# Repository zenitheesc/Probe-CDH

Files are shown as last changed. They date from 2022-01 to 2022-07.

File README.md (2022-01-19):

# Probe-CDH
<h1 align="center" style="color:white; background-color:black">Probe-CDH</h1>
<h4 align="center"> Telecommunication board for the Zenith's Stack architecture.</h4>

<p align="center">
	<a href="http://zenith.eesc.usp.br/">
    
    </a>
    <a href="https://eesc.usp.br/">
    
    </a>
    <a href="https://github.com/zenitheesc/Probe-CDH/blob/main/LICENSE">
    
    </a>
    <a href="https://github.com/zenitheesc/Probe-CDH/issues">
    
    </a>
    <a href="https://github.com/zenitheesc/Probe-CDH/commits/main">
    
    </a>
    <a href="https://github.com/zenitheesc/Probe-CDH/graphs/contributors">
    
    </a>
    <a href="https://github.com/zenitheesc/Probe-CDH/commits/main">
    
    </a>
    <a href="https://github.com/zenitheesc/Probe-CDH/issues">
    
    </a>
    <a href="https://github.com/zenitheesc/Probe-CDH/pulls">
    
    </a>
</p>

<p align="center">
    <a href="#environment-and-tools">Environment and Tools</a> •
    <a href="#Z-Hub">Z-Hub</a> •
    <a href="#Block-Diagram">Block Diagram</a> •
    <a href="#Schematic">Schematic</a> • 
    <a href="#Board">Board</a>
</p>

## Environment and tools

This board was designed using KiCad 5.1.10.

## Block Diagram

<p align = "center">
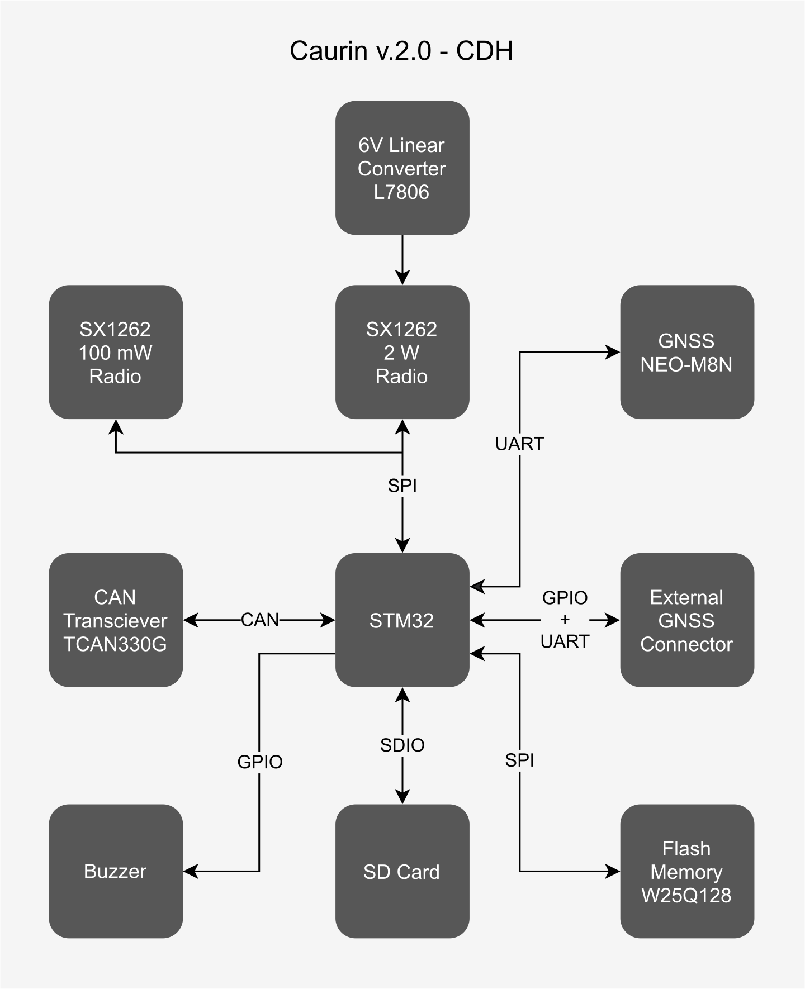
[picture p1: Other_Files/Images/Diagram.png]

</p>

## Z-Hub

This board contains a Stack Connector, with the 2021 Z-Hub pinout.

<table align = "center">
  <thead>
    <tr>
      <th colspan=2>   Z-Hub 2021   </th>
    </tr>
  </thead>
  <tbody>
    <tr>
      <td>GND</td>
      <td>GND</td>
    </tr>
    <tr>
      <td>GND</td>
      <td>GND</td>
    </tr>
    <tr>
      <td>BAT+</td>
      <td>BAT+</td>
    </tr>
    <tr>
      <td>SOl+</td>
      <td>SOl-</td>
    </tr>
    <tr>
      <td>5V</td>
      <td>5V</td>
    </tr>
    <tr>
      <td>3V3</td>
      <td>3V3</td>
    </tr>
    <tr>
      <td>MISO1</td>
      <td>MOSI1</td>
    </tr>
    <tr>
      <td>SCK1</td>
      <td>CAN_H</td>
    </tr>
    <tr>
      <td>SDA </td>
      <td>CAN_L</td>
    </tr>
    <tr>
      <td>SCL</td>
      <td>CE02</td>
    </tr>
    <tr>
      <td>CE11</td>
      <td>CE12</td>
    </tr>
    <tr>
      <td>SDA1</td>
      <td>SCL1</td>
    </tr>
    <tr>
      <td>SDA2</td>
      <td>SCL2</td>
    </tr>
    <tr>
      <td>TX1</td>
      <td>RX1</td>
    </tr>
    <tr>
      <td>TX2</td>
      <td>RX2</td>
    </tr>
    <tr>
      <td>DIG1</td>
      <td>DIG6</td>
    </tr>
    <tr>
      <td>ALRT1</td>
      <td>/CHRG</td>
    </tr>
    <tr>
      <td>PWM</td>
      <td>DIG8</td>
    </tr>
    <tr>
      <td>/FAULT</td>
      <td>DIG9</td>
    </tr>
    <tr>
      <td>DIG5</td>
      <td>DIG10</td>
    </tr>
  </tbody>
</table>

## Schematic

The design was separated in hierarchical sheets to accommodate all components in an orderly way.

The first page contains the STM32L476 with all its accompanying circuits; crystals, debugging LED, Boot solder jumper, decoupling capacitors and reset buttons. On the same page you find the stack connector along with a programming and debugging connector and an external GPS connector (can also be used for UART communication with external devices, it’s bad but it’s there).

<p align = "center">
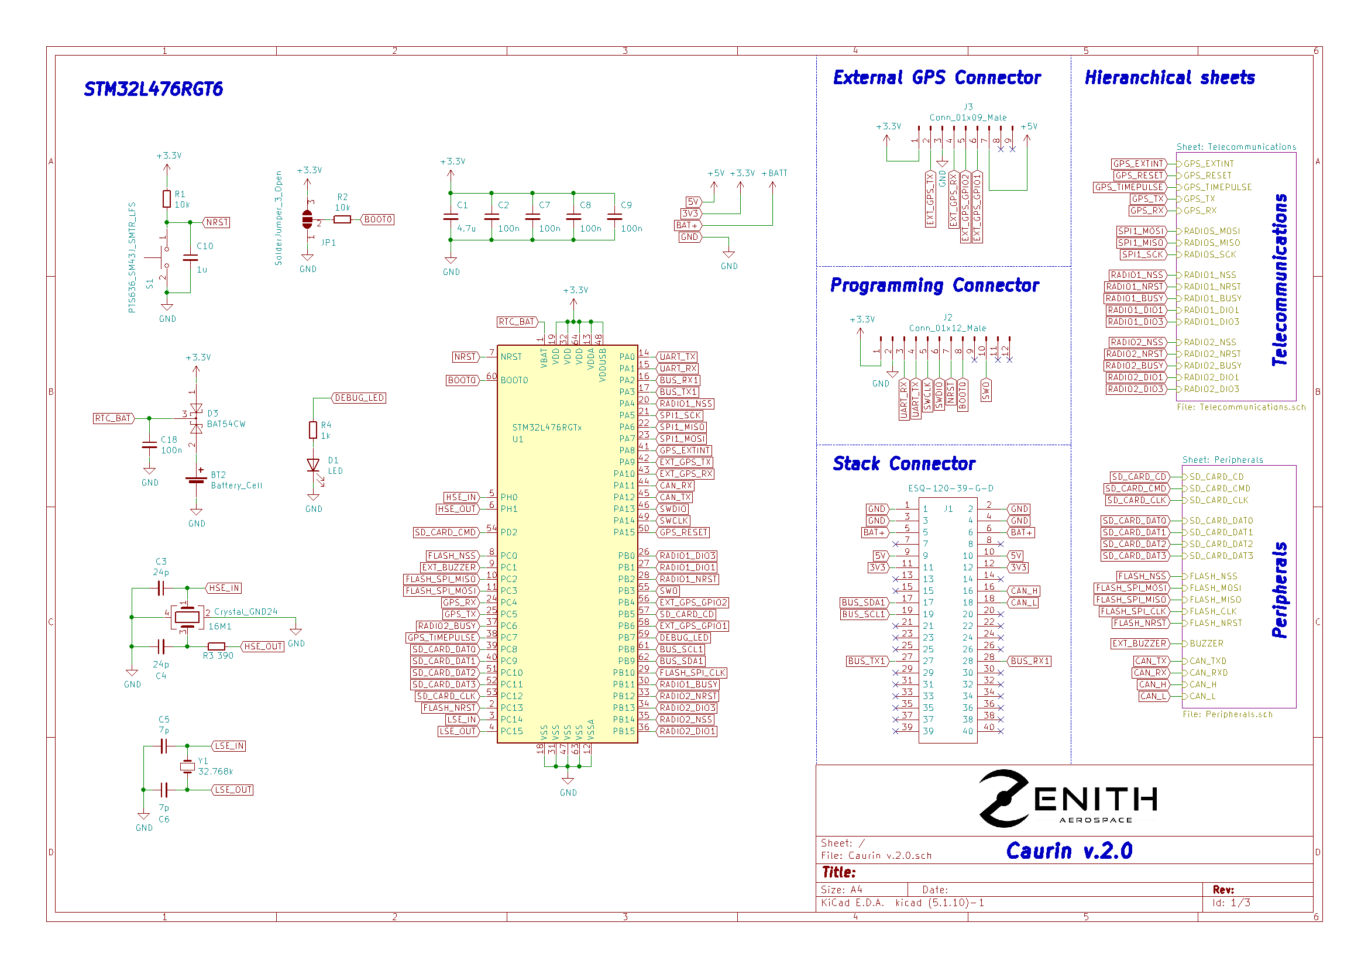
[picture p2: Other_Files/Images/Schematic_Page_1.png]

</p>

The second page contains the two LoRa and (G)FSK radios, one capable of 2 W off transmission power when fed with 6 V (obtained with the linear regulator), and the other capable of 160 mW, used as a backup or low power option. Both of them are based on the Semtech SX1262 transceiver, for operation at 915 MHz. The u-blox NEO-M8N also lives on this page, with its backup super capacitor for hot starts.

<p align = "center">
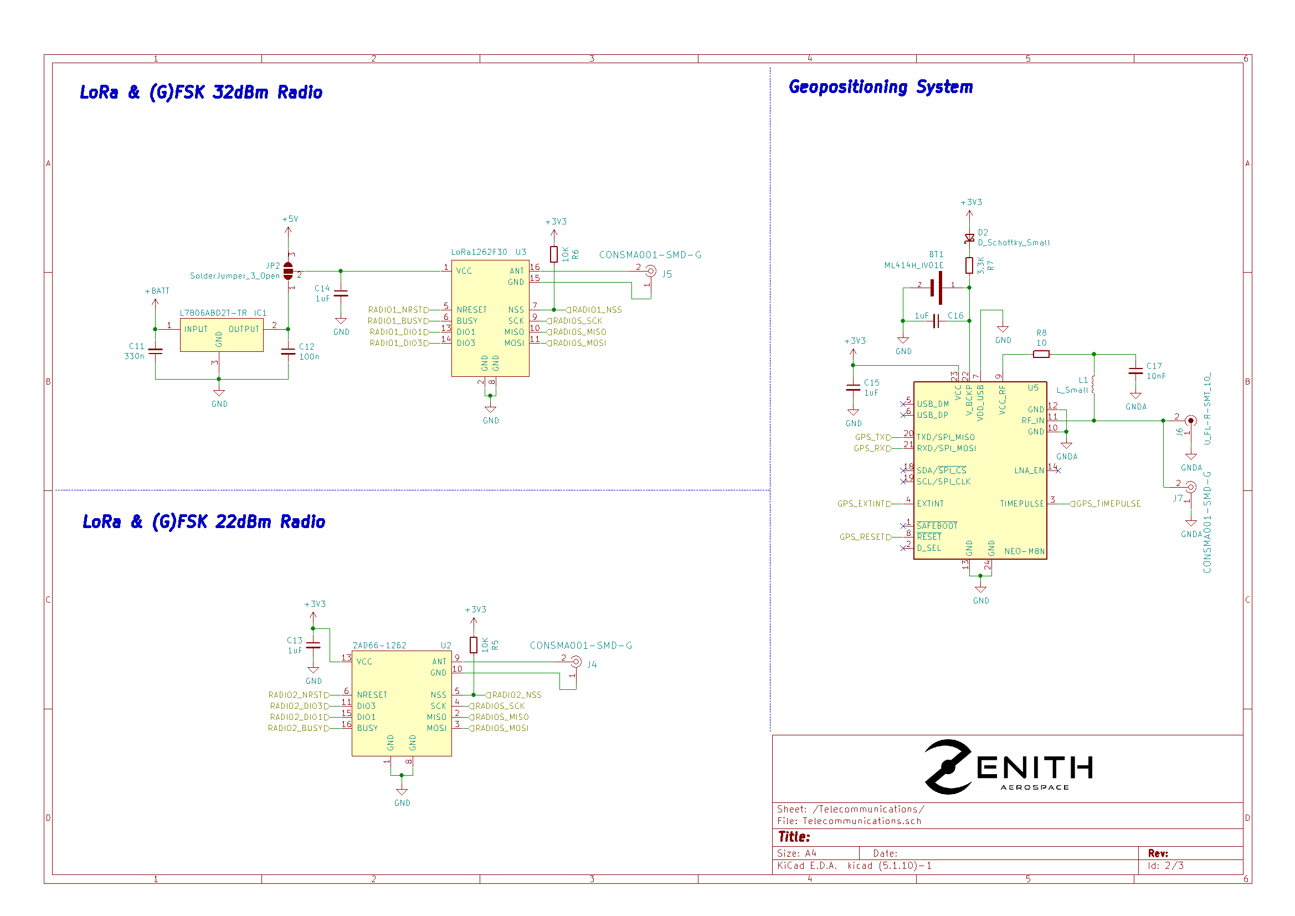
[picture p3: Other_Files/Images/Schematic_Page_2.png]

</p>

The last page houses the remaining peripherals which include the SD Card, the 128 Mb Flash, the CAN Transceiver and the buzzer connector with its mosfet, which may also be used as an external actuator with a max current of 1 A (the mosfet actually handles up to 1,5 A but let’s not push it too far).  

<p align = "center">
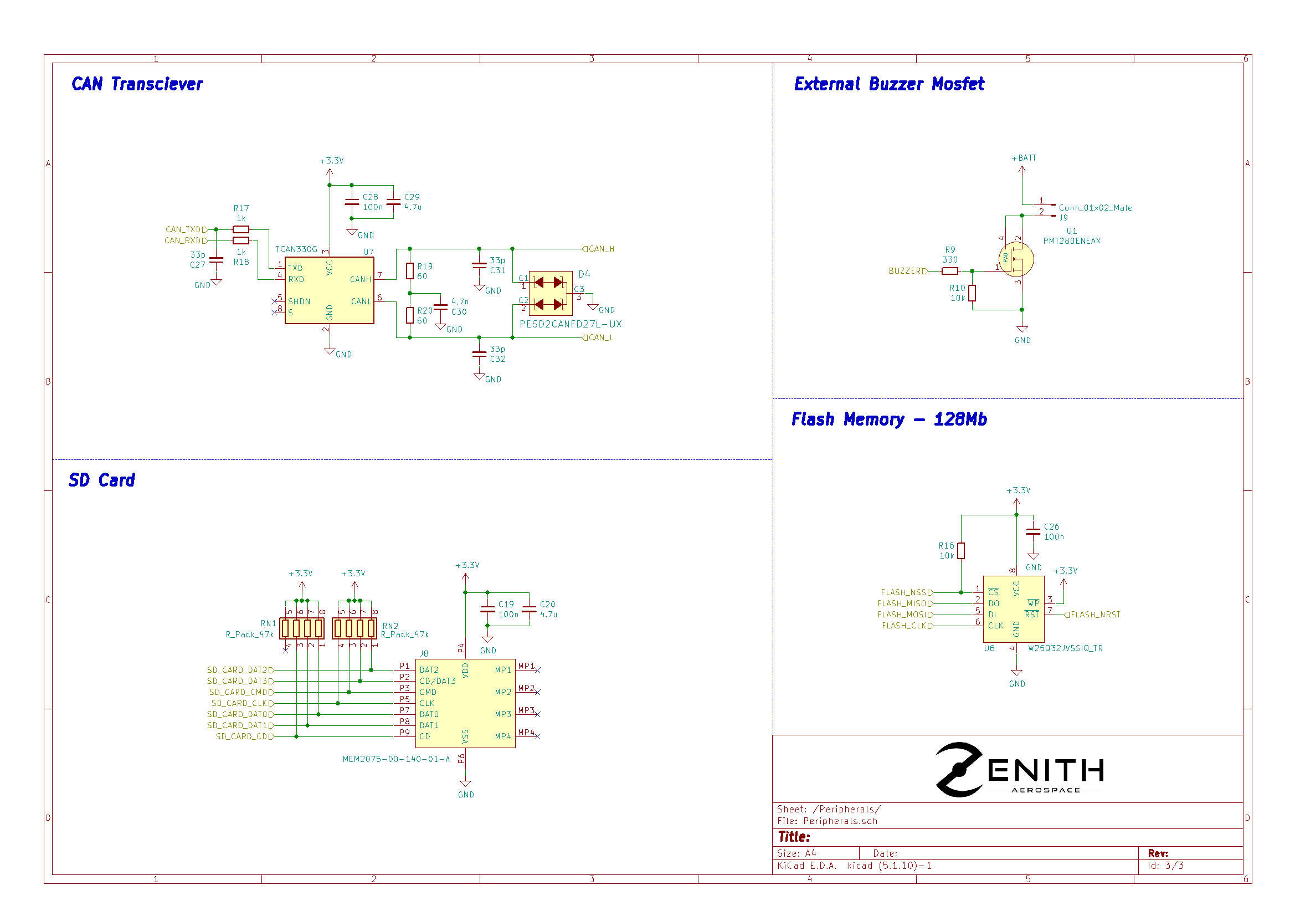
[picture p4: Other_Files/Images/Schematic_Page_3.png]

</p>

## Board

<p align = "center">
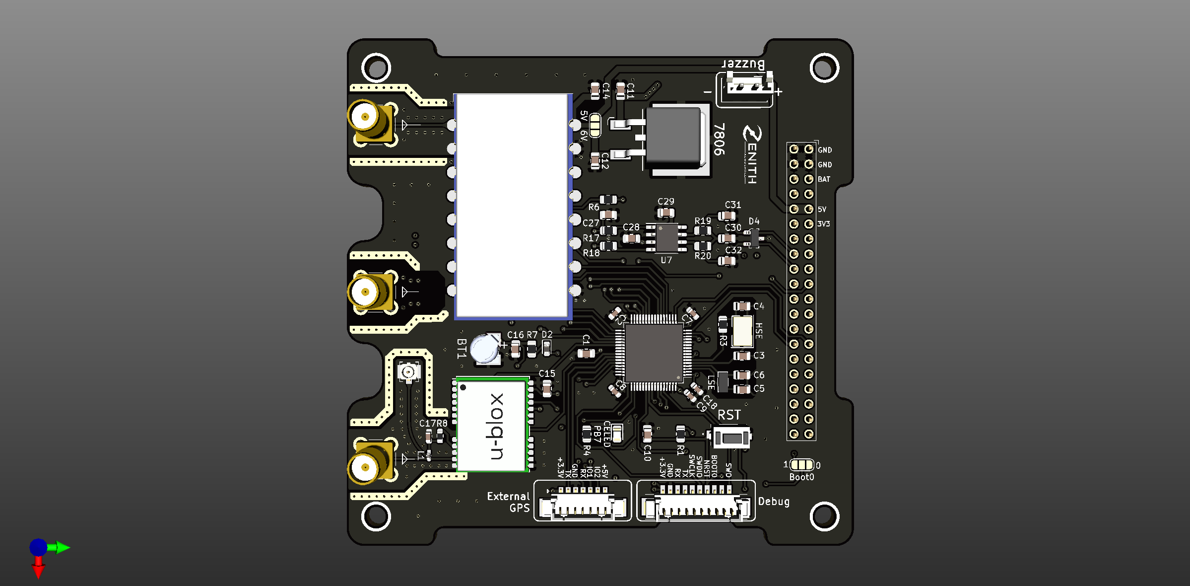
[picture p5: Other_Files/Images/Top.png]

</p>

<p align = "center">
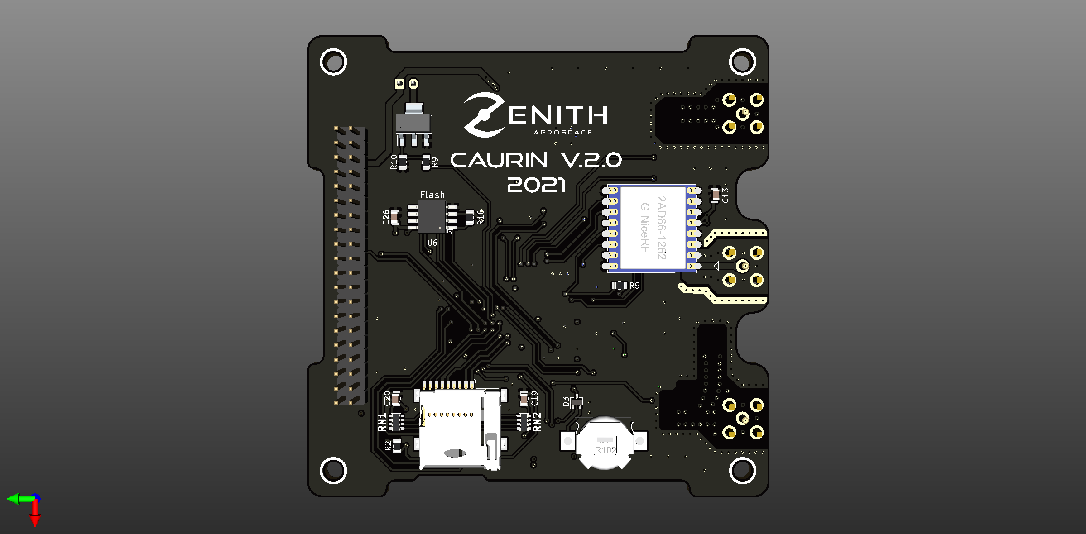
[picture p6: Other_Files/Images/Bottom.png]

</p>

<p align = "center">
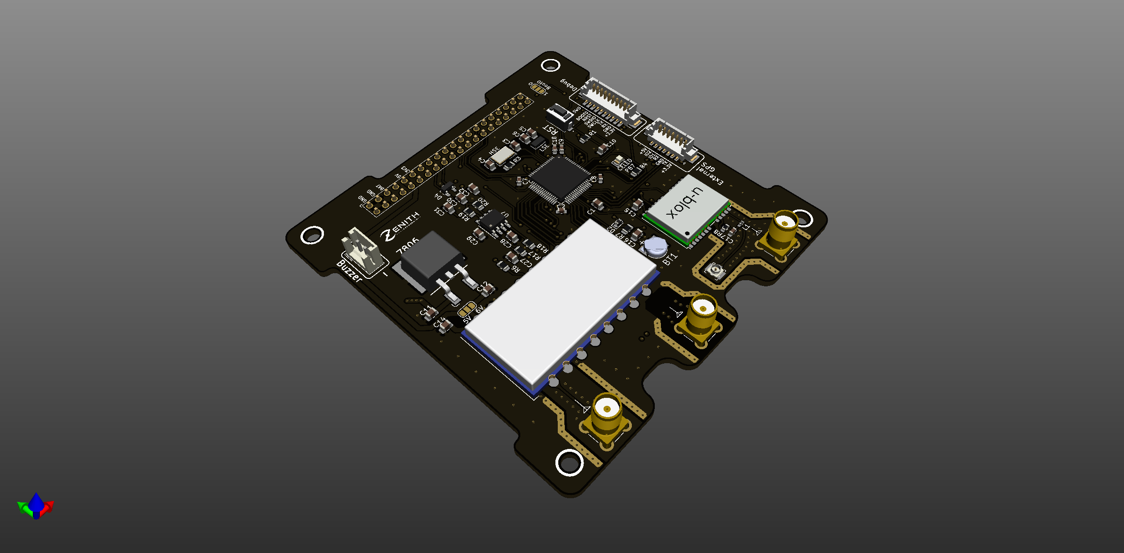
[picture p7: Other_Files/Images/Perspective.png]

</p>

---

<p align="center">
    <a href="http://zenith.eesc.usp.br">
    
    </a> 
    <a href="https://www.facebook.com/zenitheesc">
    
    </a> 
    <a href="https://www.instagram.com/zenith_eesc/">
    
    </a>

</p>
<p align = "center">
<a href="zenith.eesc@gmail.com">zenith.eesc@gmail.com</a>
</p>

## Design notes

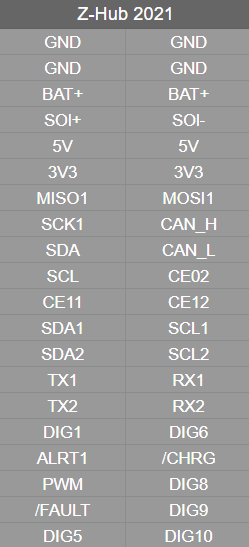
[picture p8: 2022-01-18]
Other_Files/Images/Z-Hub.png

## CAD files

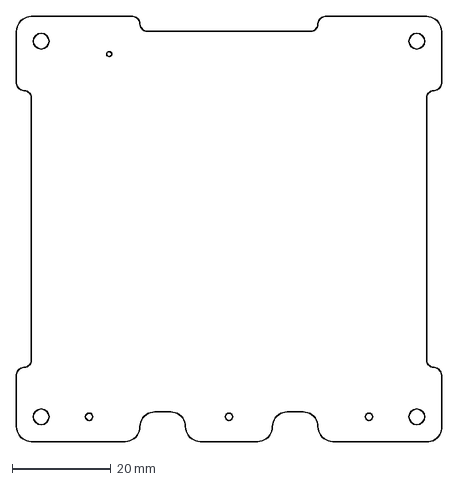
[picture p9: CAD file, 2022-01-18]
KiCad_Files/ModelStack.dxf
86.0 x 86.0 mm

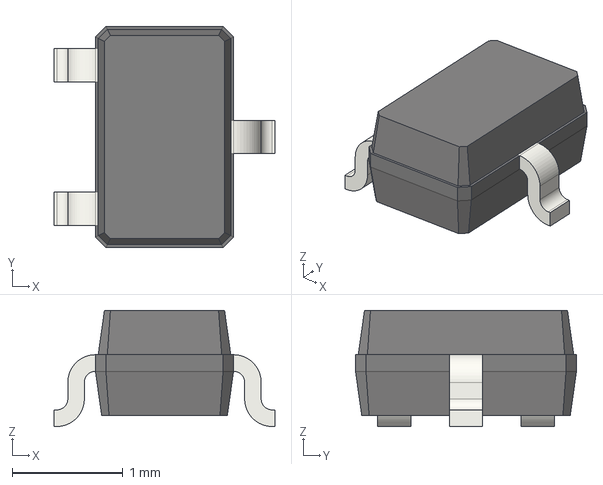
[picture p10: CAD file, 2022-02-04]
KiCad_Files/shapes3D/SOT-323_SC-70.step
2.00 x 2.00 x 1.05 mm

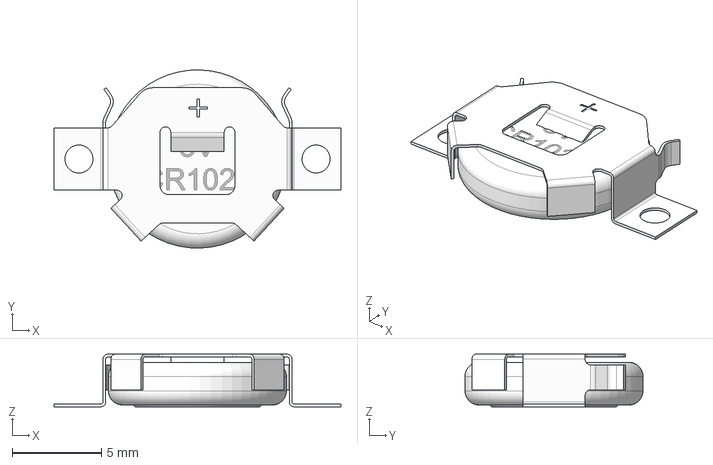
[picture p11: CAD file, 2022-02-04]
KiCad_Files/shapes3D/keystone-PN3030TR+ButtonCell.step
16.1 x 10.00 x 2.95 mm

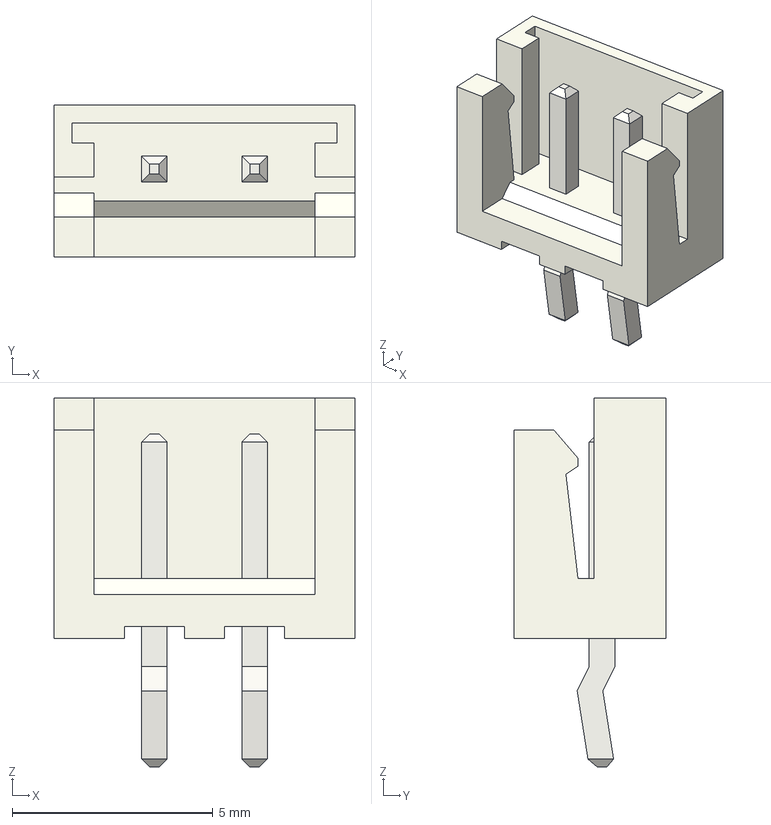
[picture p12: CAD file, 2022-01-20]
KiCad_Files/shapes3D/JST_EH_B2B-EH-A_1x02_P2.50mm_Vertical.step
7.50 x 3.80 x 9.20 mm

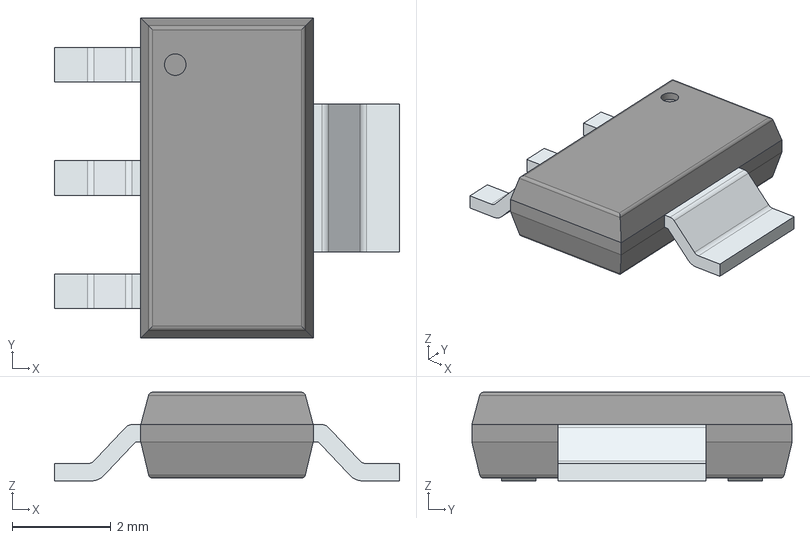
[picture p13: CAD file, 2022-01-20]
KiCad_Files/shapes3D/PMT280ENEAX.stp
7.00 x 6.50 x 1.80 mm
PinsArrayL
FilletPinR

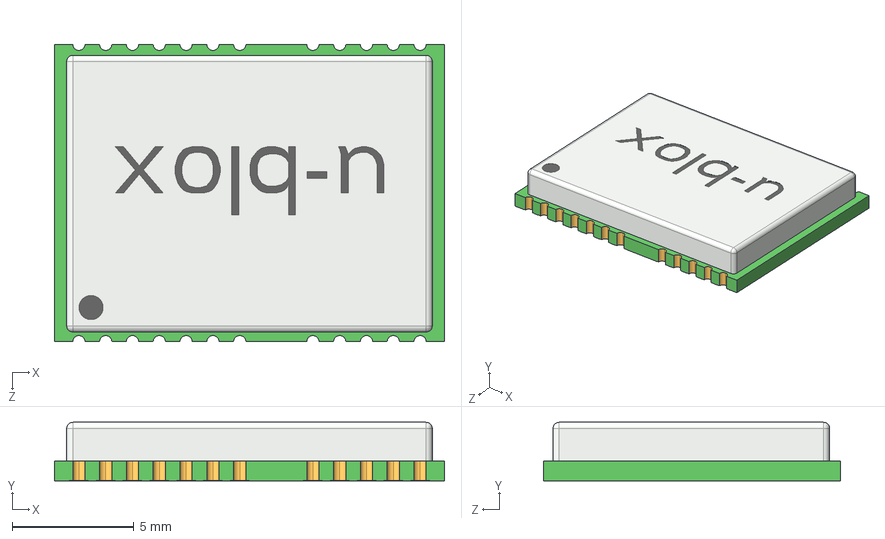
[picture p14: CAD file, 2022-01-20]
KiCad_Files/shapes3D/User Library-neo-m8n.step
16.0 x 2.40 x 12.2 mm

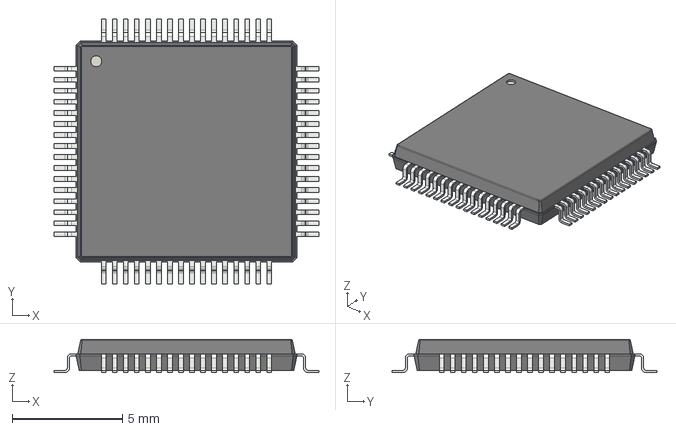
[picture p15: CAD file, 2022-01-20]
KiCad_Files/shapes3D/LQFP-64_10x10mm_P0.5mm.step
12.0 x 12.0 x 1.50 mm

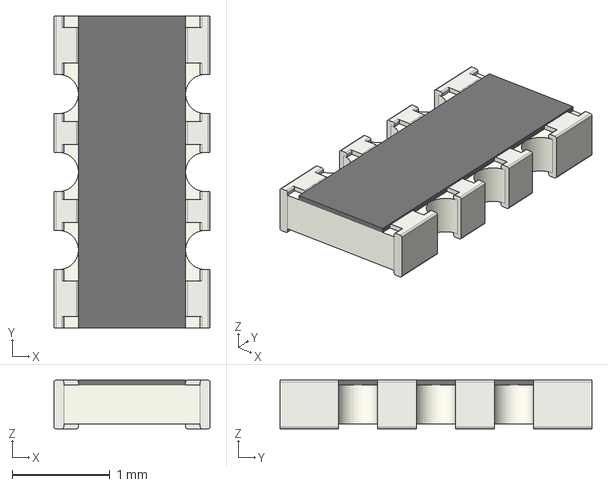
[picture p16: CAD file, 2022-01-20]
KiCad_Files/shapes3D/R_Array_Convex_4x0603.step
1.60 x 3.20 x 0.5 mm

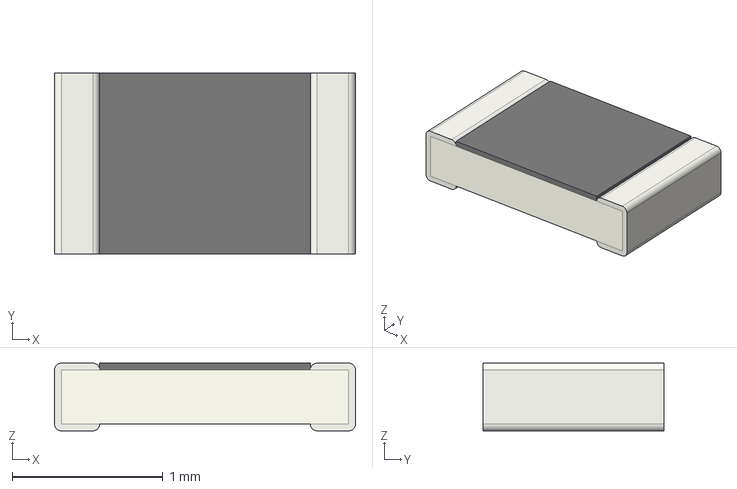
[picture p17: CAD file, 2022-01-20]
KiCad_Files/shapes3D/R_0805_2012Metric.step
2.00 x 1.20 x 0.45 mm

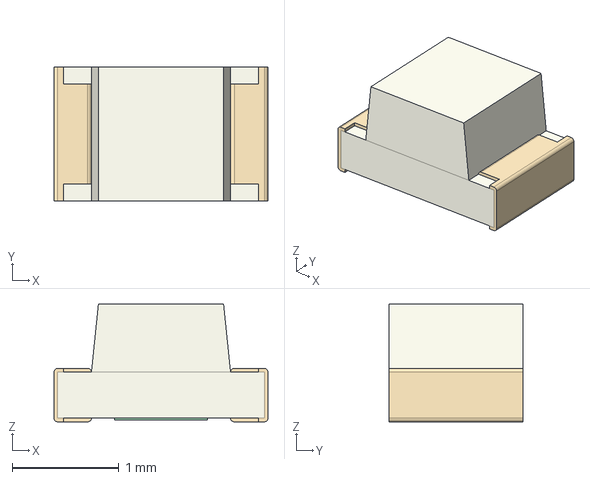
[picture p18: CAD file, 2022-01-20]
KiCad_Files/shapes3D/LED_0805_2012Metric.step
2.00 x 1.25 x 1.10 mm

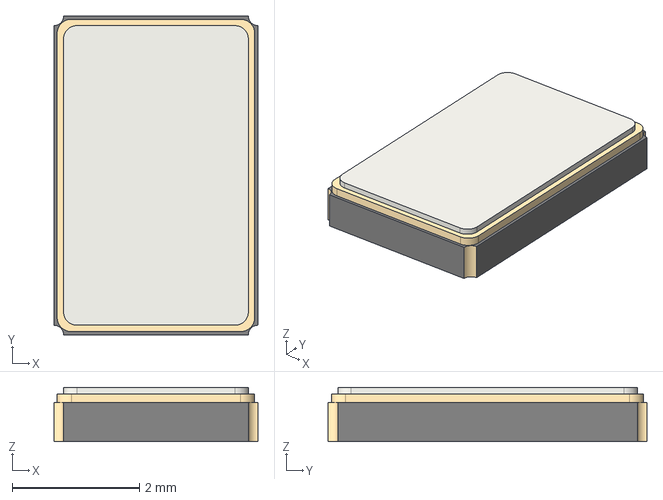
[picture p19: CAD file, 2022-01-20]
KiCad_Files/shapes3D/Crystal_SMD_4Pin_5x3.2mm.step
3.20 x 5.00 x 0.85 mm

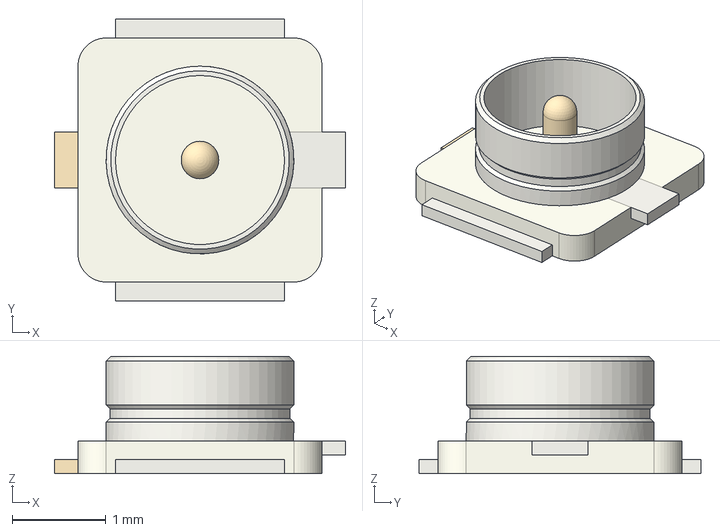
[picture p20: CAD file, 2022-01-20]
KiCad_Files/shapes3D/U.FL_Hirose_U.FL-R-SMT-1_Vertical.step
3.10 x 3.00 x 1.25 mm

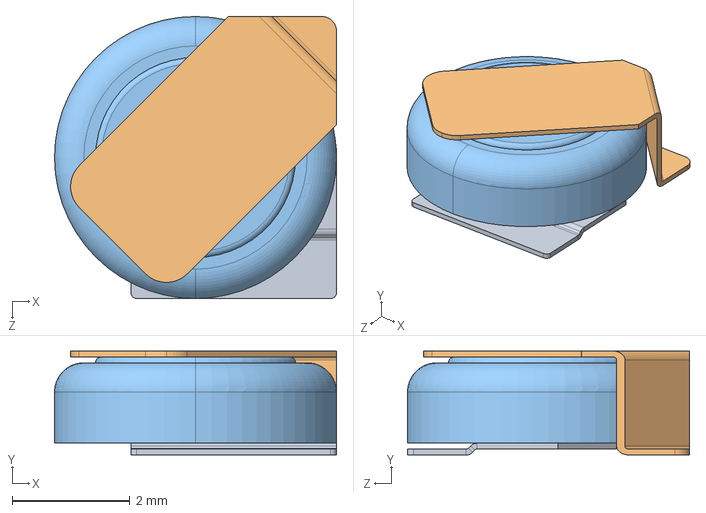
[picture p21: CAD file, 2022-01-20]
KiCad_Files/shapes3D/ML414H IV01E--3DModel-STEP-56544.step
4.80 x 1.77 x 4.80 mm

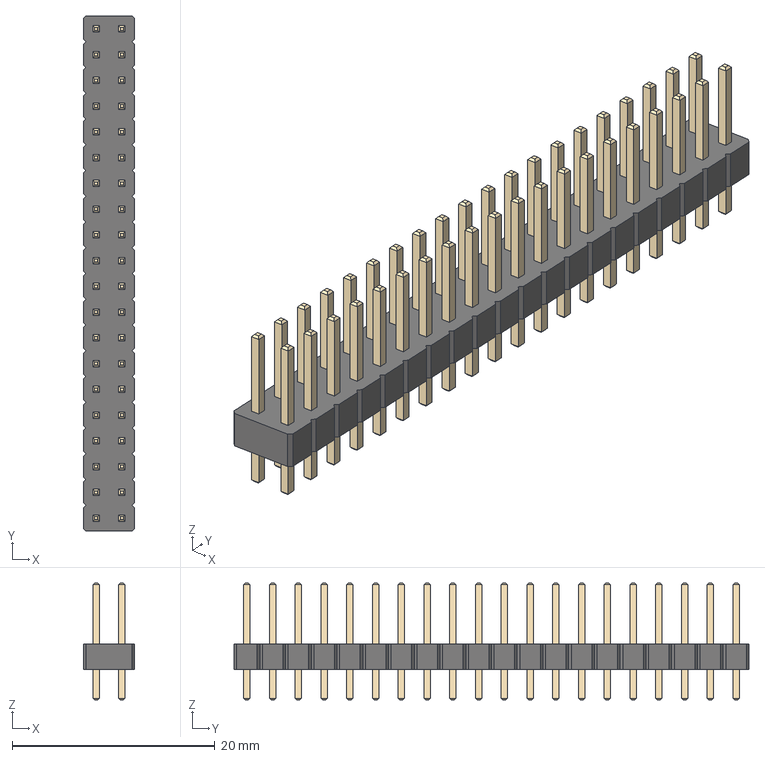
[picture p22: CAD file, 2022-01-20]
KiCad_Files/shapes3D/PinHeader_2x20_P2.54mm_Vertical.step
5.08 x 50.8 x 11.5 mm

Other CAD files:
KiCad_Files/shapes3D/2AD6-1262 G-NiceRF.step
KiCad_Files/shapes3D/SO-8_5.3x6.2mm_P1.27mm.step
KiCad_Files/shapes3D/LoRa126XF30.step
KiCad_Files/shapes3D/Molex - 73391-0060.step
KiCad_Files/shapes3D/533980771 recolored.step
KiCad_Files/shapes3D/533981071 recolored.step
KiCad_Files/shapes3D/C_0603_1608Metric.step
KiCad_Files/shapes3D/C_0805_2012Metric.step
KiCad_Files/shapes3D/Crystal_SMD_MicroCrystal_CC7V-T1A-2Pin_3.2x1.5mm.step
KiCad_Files/shapes3D/D2PAK-2 L7805.step
KiCad_Files/shapes3D/D_0603_1608Metric.step
KiCad_Files/shapes3D/L_0402_1005Metric.step
KiCad_Files/shapes3D/MEM2075-00-140-01-A.stp
KiCad_Files/shapes3D/PTS636_SM43J_SMTR_LFS.stp
KiCad_Files/shapes3D/R_0603_1608Metric.step
KiCad_Files/shapes3D/SOIC-8_3.9x4.9mm_P1.27mm.step
KiCad_Files/shapes3D/SOT-23.step

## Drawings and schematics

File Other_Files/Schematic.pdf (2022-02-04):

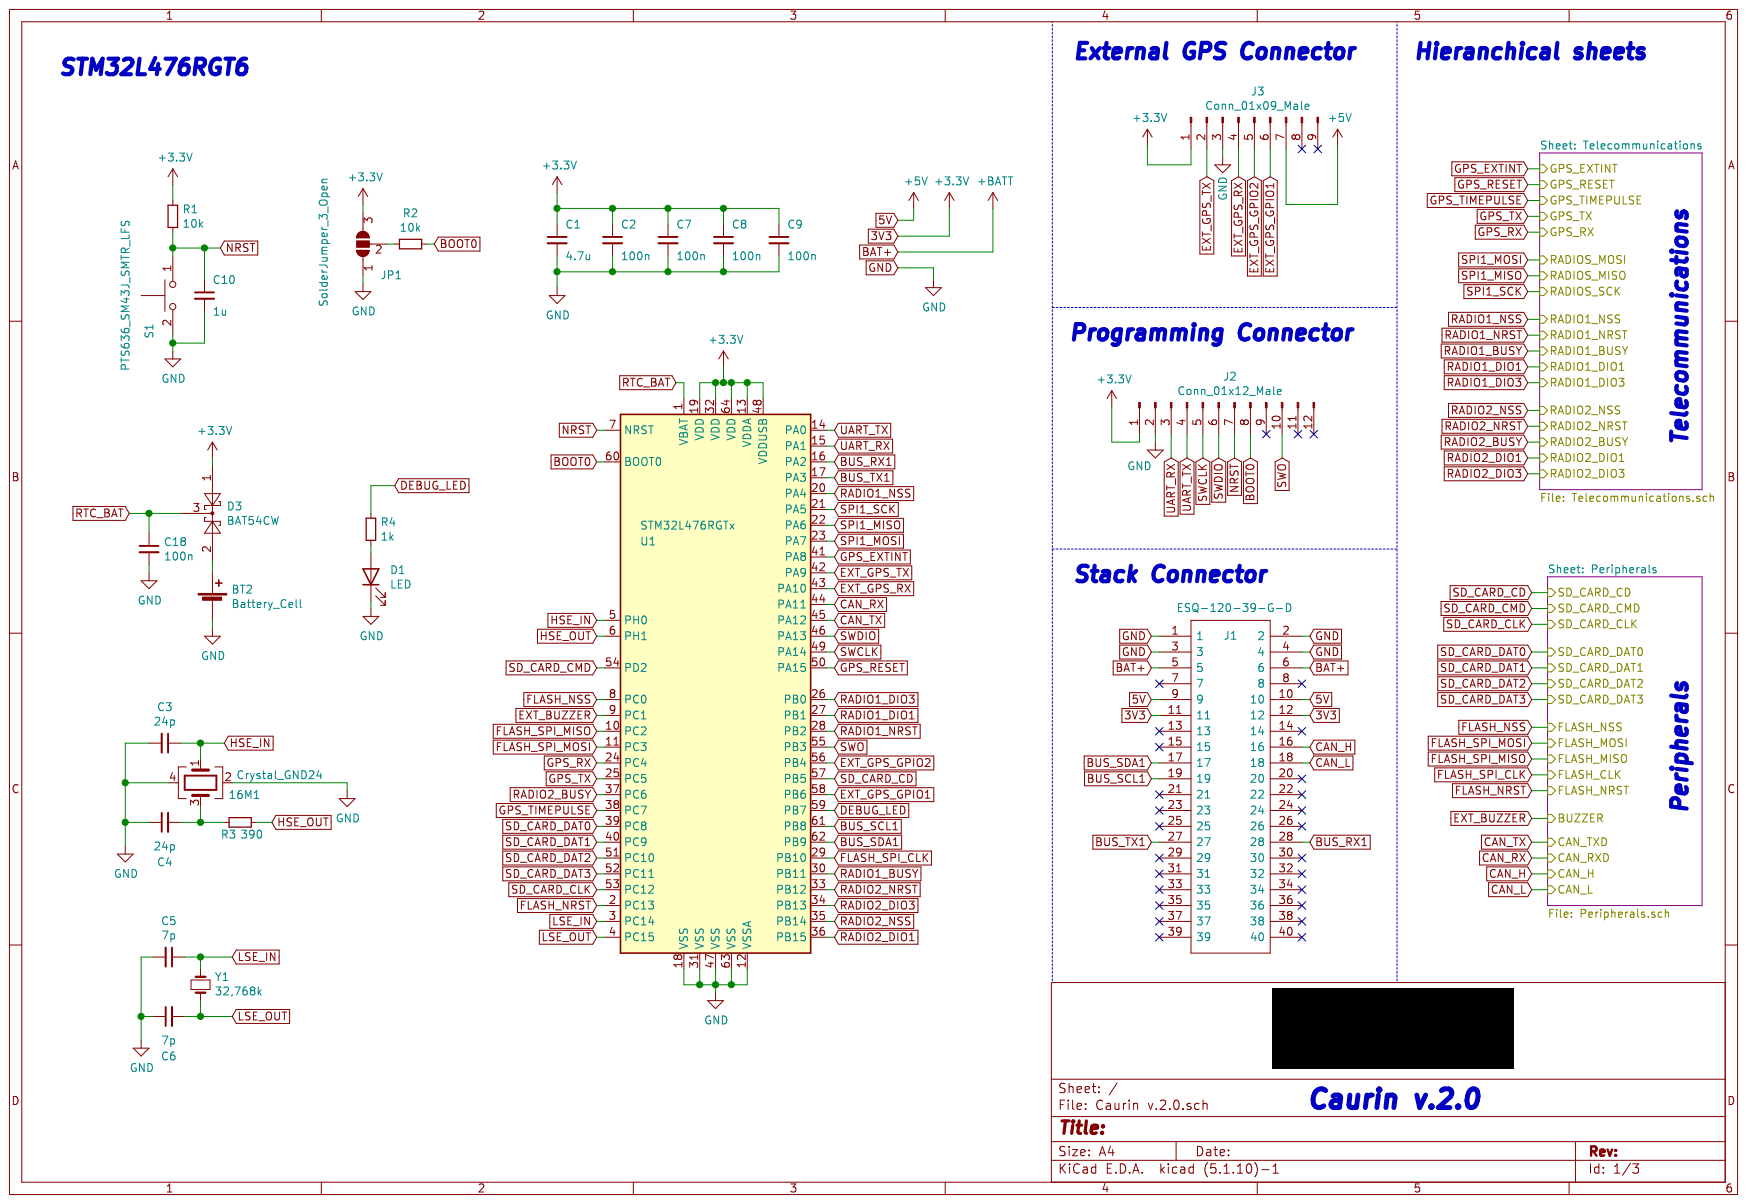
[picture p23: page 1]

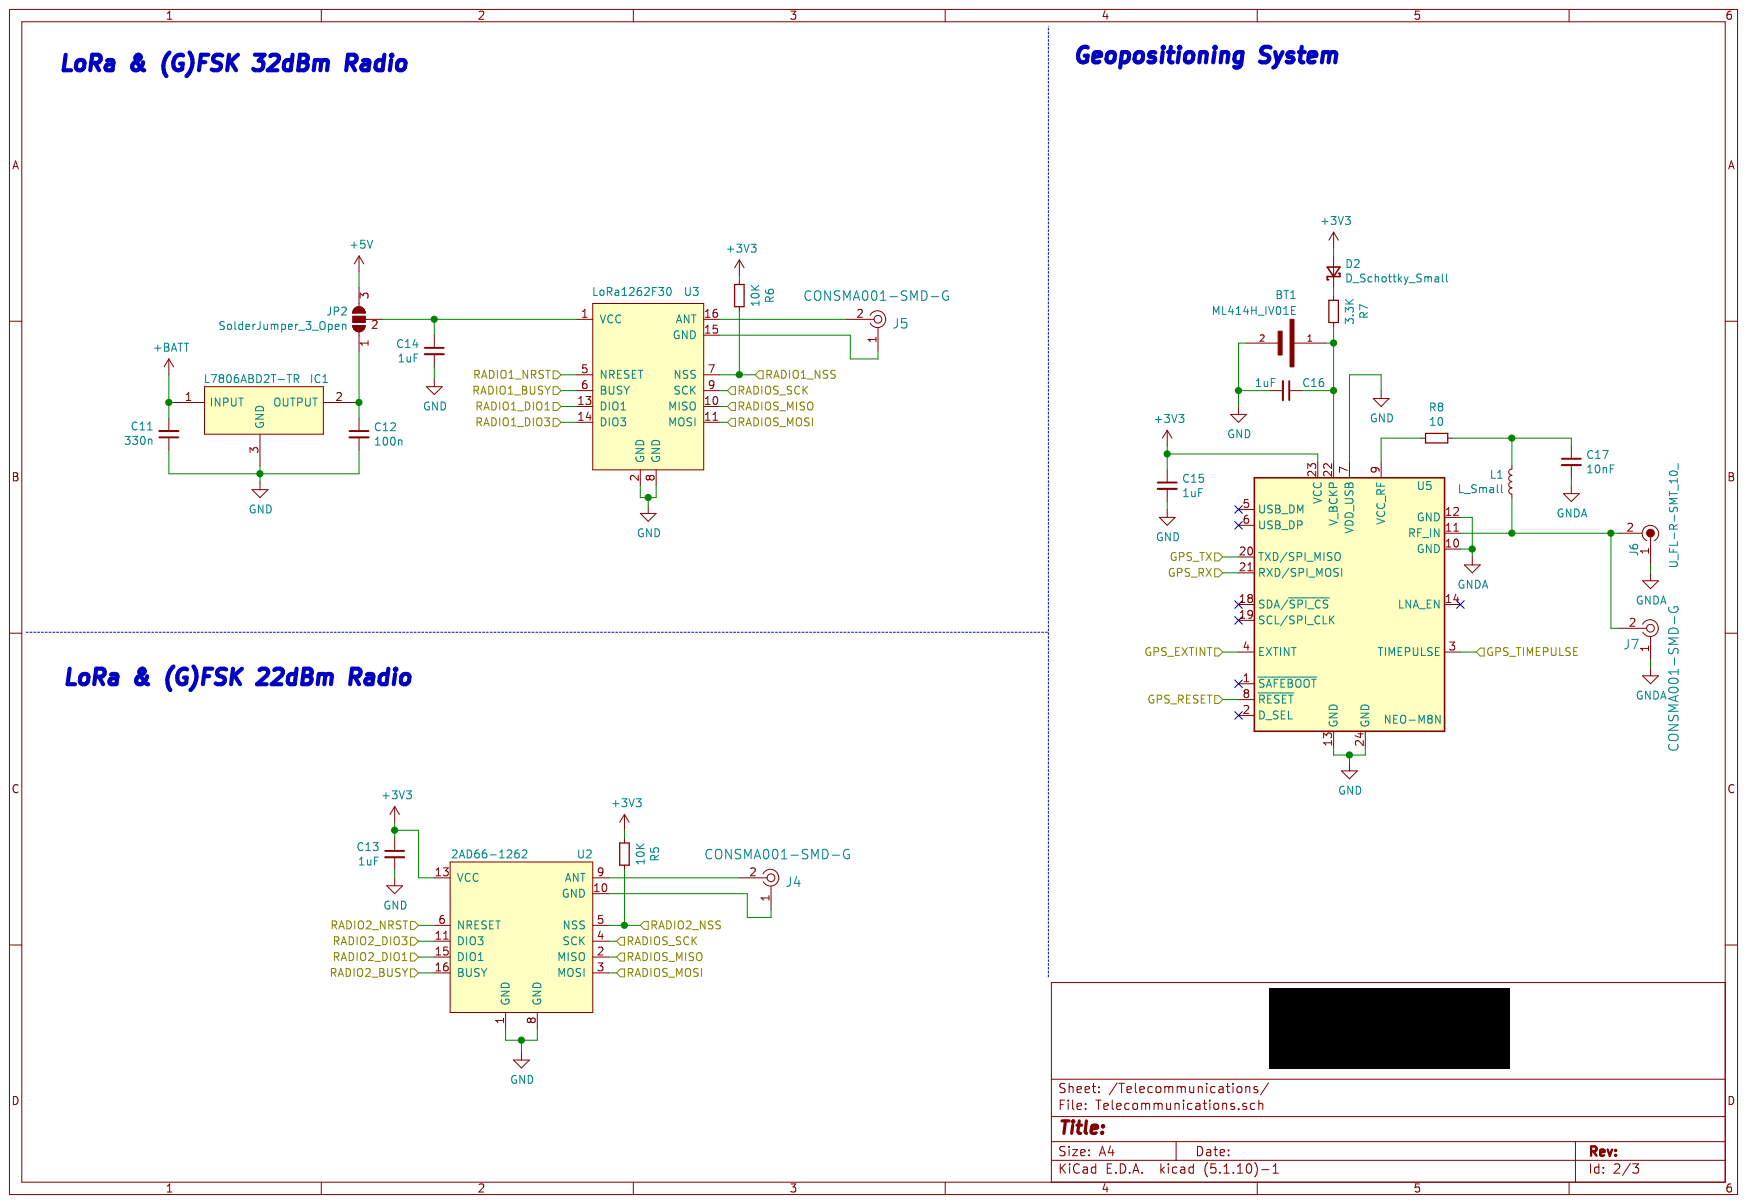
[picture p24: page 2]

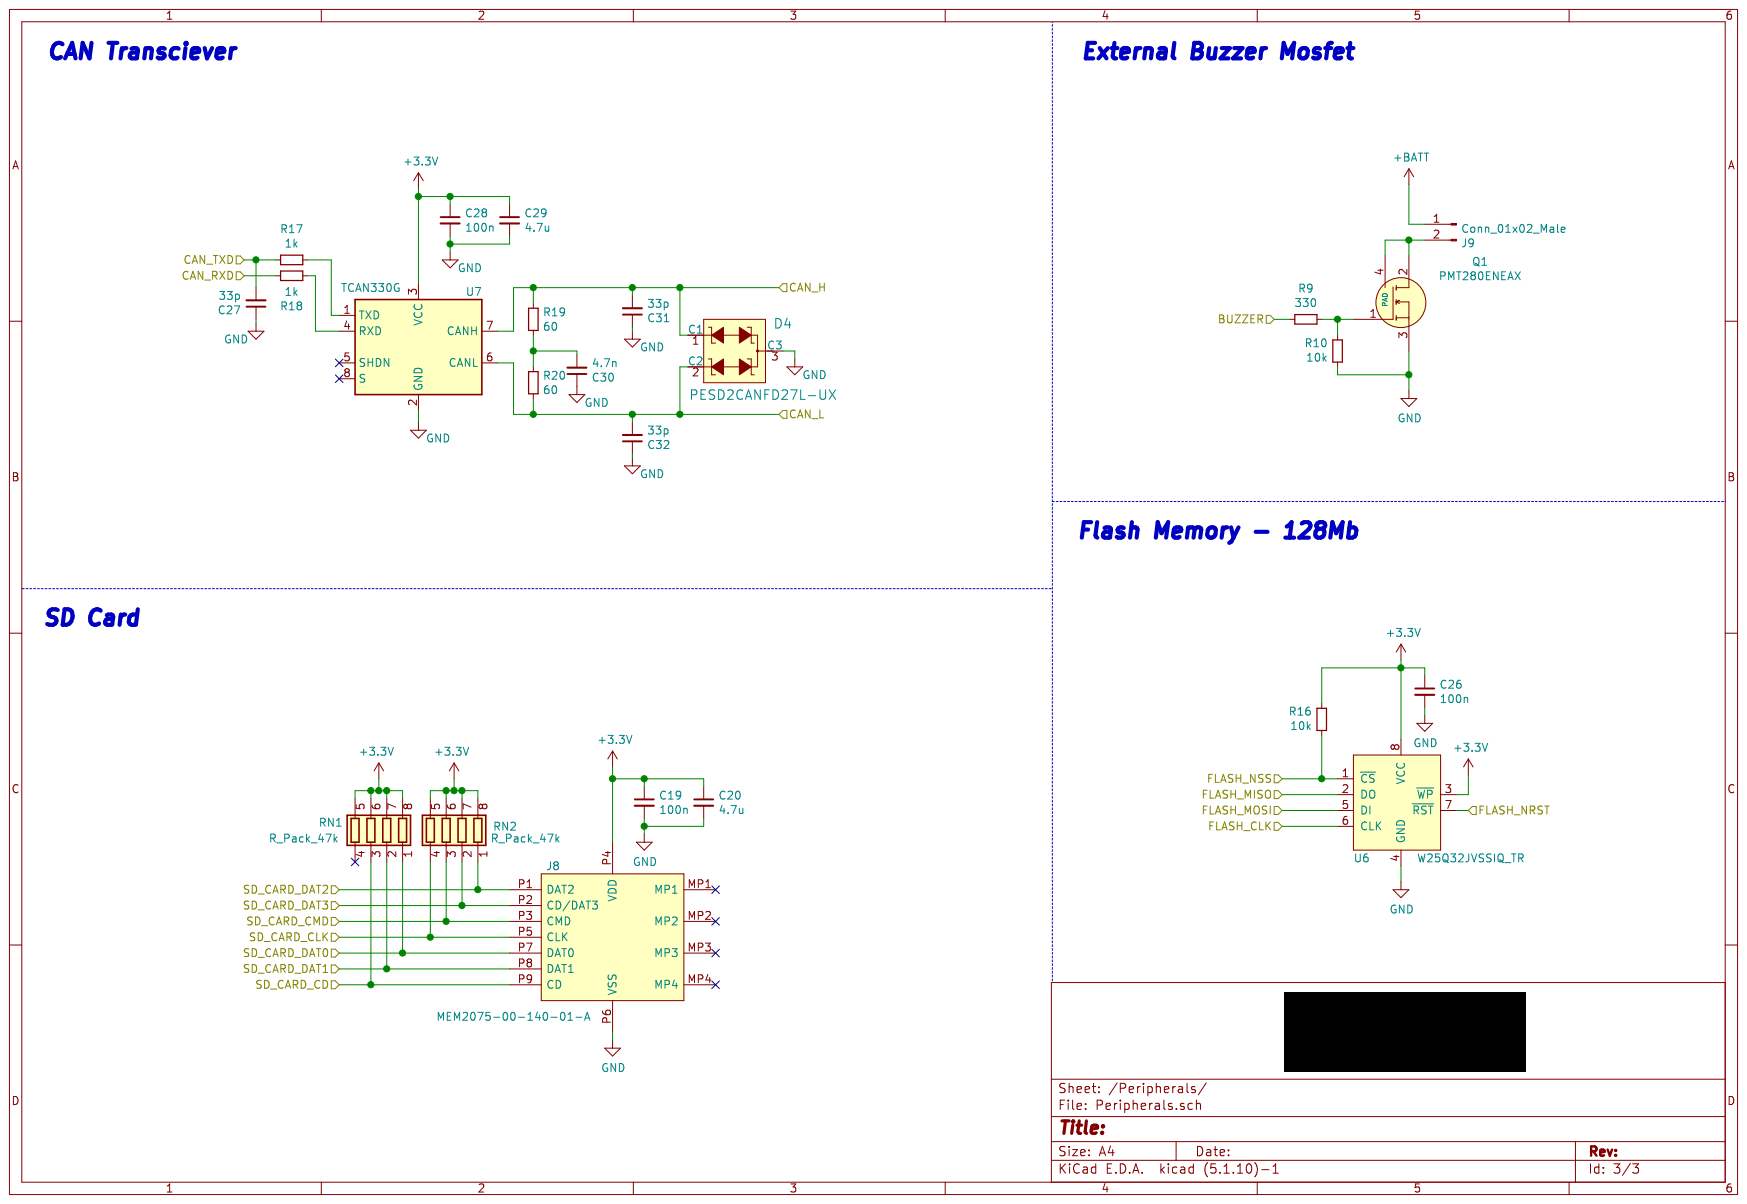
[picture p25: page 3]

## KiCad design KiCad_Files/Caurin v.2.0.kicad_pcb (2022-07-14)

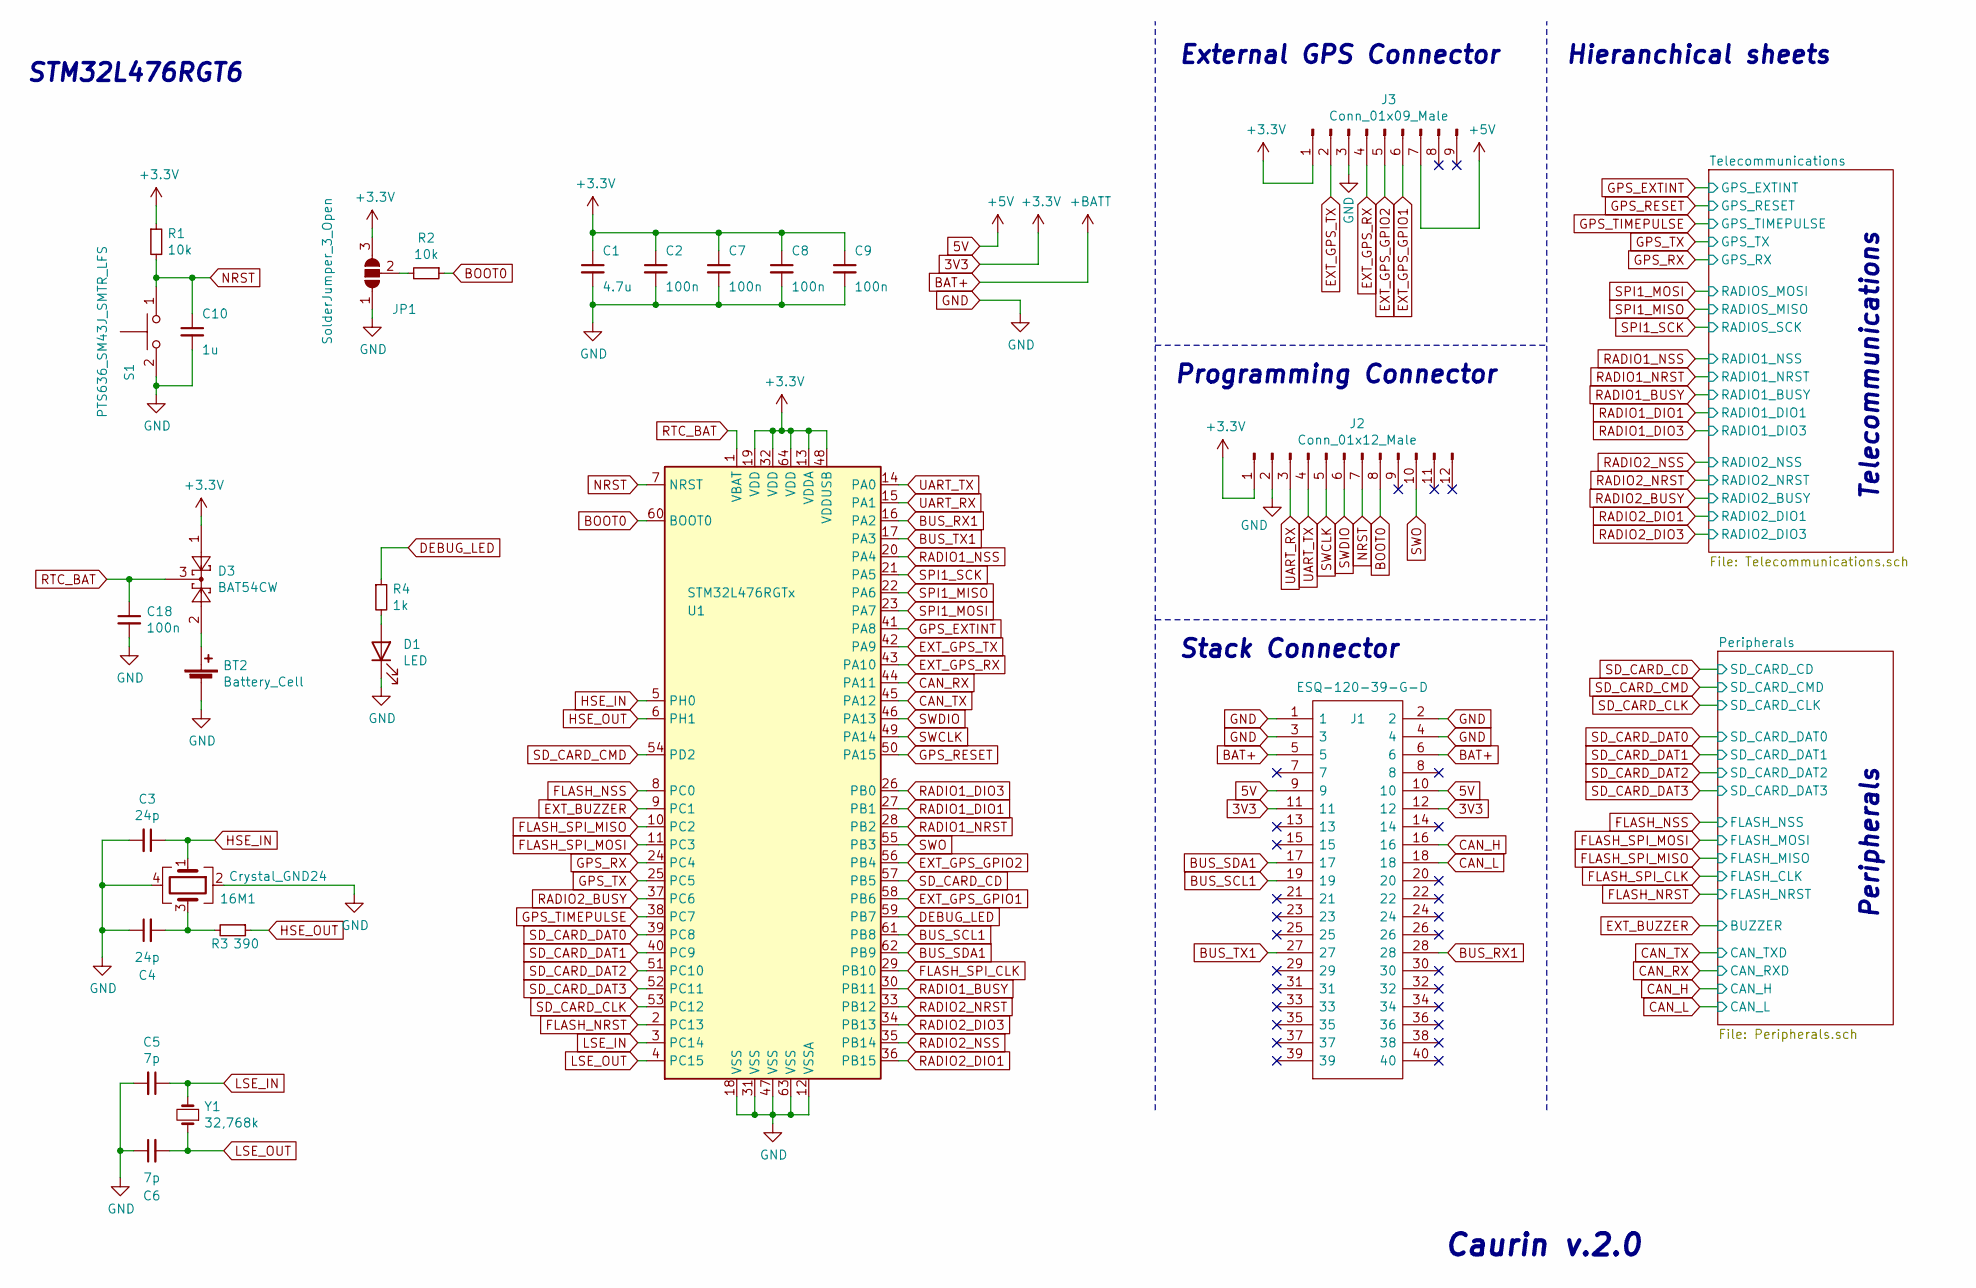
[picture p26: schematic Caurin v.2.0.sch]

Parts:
16M1: Crystal_GND24; Crystal_SMD_5032-4Pin_5.0x3.2mm_Hand_Soldering
BT2: Battery_Cell; 3030
C1: 4.7u; C_0805_2012Metric
C2, C7, C8, C9, C18: 100n; C_0603_1608Metric
C3, C4: 24p; C_0805_2012Metric
C5, C6: 7p; C_0805_2012Metric
C10: 1u; C_0805_2012Metric
D1: LED; LED_0805_2012Metric
D3: BAT54CW; SOT-323_SC-70
J1: ESQ-120-39-G-D; ESQ-120-Y-X-D; Mouser Part Number 200-ESQ12039GD
J2: Conn_01x12_Male; 532611071
J3: Conn_01x09_Male; 533980771
JP1: SolderJumper_3_Open; SolderJumper-3_P1.3mm_Open_RoundedPad1.0x1.5mm_NumberLabels
R1, R2: 10k; R_0805_2012Metric
R3: 390; R_0805_2012Metric
R4: 1k; R_0805_2012Metric
S1: PTS636_SM43J_SMTR_LFS; PTS636SM43JSMTRLFS; Mouser Part Number 611-PTS636SM43JSMTRL
U1: STM32L476RGTx; LQFP-64_10x10mm_P0.5mm
Y1: 32,768k; Crystal_SMD_3215-2Pin_3.2x1.5mm

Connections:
5V: J1.9, J1.10, J3.7; also elsewhere on the board
BAT+: J1.5, J1.6; also elsewhere on the board
BOOT0: J2.8, R2.1, U1.60 (BOOT0)
BUS_RX1: J1.28, U1.16 (PA2)
BUS_SCL1: J1.19, U1.61 (PB8)
BUS_SDA1: J1.17, U1.62 (PB9)
BUS_TX1: J1.27, U1.17 (PA3)
CAN_H: J1.16; also elsewhere on the board
CAN_L: J1.18; also elsewhere on the board
CAN_RX: U1.44 (PA11); also elsewhere on the board
CAN_TX: U1.45 (PA12); also elsewhere on the board
DEBUG_LED: R4.1, U1.59 (PB7)
EXT_BUZZER: U1.9 (PC1); also elsewhere on the board
EXT_GPS_GPIO1: J3.6, U1.58 (PB6)
EXT_GPS_GPIO2: J3.5, U1.56 (PB4)
EXT_GPS_RX: J3.4, U1.43 (PA10)
EXT_GPS_TX: J3.2, U1.42 (PA9)
FLASH_NRST: U1.2 (PC13); also elsewhere on the board
FLASH_NSS: U1.8 (PC0); also elsewhere on the board
FLASH_SPI_CLK: U1.29 (PB10); also elsewhere on the board
FLASH_SPI_MISO: U1.10 (PC2); also elsewhere on the board
FLASH_SPI_MOSI: U1.11 (PC3); also elsewhere on the board
GND: 16M1.2, 16M1.4, BT2.2 (-), C1.2, C2.2, C3.2, C4.1, C5.2, C6.1, C7.2, C8.2, C9.2, C10.2, C18.2, D1.1 (K), J1.1, J1.2, J1.3, J1.4, J2.2, J3.3, JP1.1 (A), S1.2, U1.12 (VSSA), U1.18 (VSS), U1.31 (VSS), U1.47 (VSS), U1.63 (VSS); also elsewhere on the board
GPS_EXTINT: U1.41 (PA8); also elsewhere on the board
GPS_RESET: U1.50 (PA15); also elsewhere on the board
GPS_RX: U1.24 (PC4); also elsewhere on the board
GPS_TIMEPULSE: U1.38 (PC7); also elsewhere on the board
GPS_TX: U1.25 (PC5); also elsewhere on the board
HSE_IN: 16M1.1, C3.1, U1.5 (PH0)
HSE_OUT: R3.1, U1.6 (PH1)
LSE_IN: C5.1, U1.3 (PC14), Y1.2
LSE_OUT: C6.2, U1.4 (PC15), Y1.1
NRST: C10.1, J2.7, R1.2, S1.1, U1.7 (NRST)
unnamed: 16M1.3, C4.2, R3.2
unnamed: BT2.1 (+), D3.2
unnamed: D1.2 (A), R4.2
unnamed: JP1.2 (C), R2.2
RADIO1_BUSY: U1.30 (PB11); also elsewhere on the board
RADIO1_DIO1: U1.27 (PB1); also elsewhere on the board
RADIO1_DIO3: U1.26 (PB0); also elsewhere on the board
RADIO1_NRST: U1.28 (PB2); also elsewhere on the board
RADIO1_NSS: U1.20 (PA4); also elsewhere on the board
RADIO2_BUSY: U1.37 (PC6); also elsewhere on the board
RADIO2_DIO1: U1.36 (PB15); also elsewhere on the board
RADIO2_DIO3: U1.34 (PB13); also elsewhere on the board
RADIO2_NRST: U1.33 (PB12); also elsewhere on the board
RADIO2_NSS: U1.35 (PB14); also elsewhere on the board
RTC_BAT: C18.1, D3.3, U1.1 (VBAT)
SD_CARD_CD: U1.57 (PB5); also elsewhere on the board
SD_CARD_CLK: U1.53 (PC12); also elsewhere on the board
SD_CARD_CMD: U1.54 (PD2); also elsewhere on the board
SD_CARD_DAT0: U1.39 (PC8); also elsewhere on the board
SD_CARD_DAT1: U1.40 (PC9); also elsewhere on the board
SD_CARD_DAT2: U1.51 (PC10); also elsewhere on the board
SD_CARD_DAT3: U1.52 (PC11); also elsewhere on the board
SPI1_MISO: U1.22 (PA6); also elsewhere on the board
SPI1_MOSI: U1.23 (PA7); also elsewhere on the board
SPI1_SCK: U1.21 (PA5); also elsewhere on the board
SWCLK: J2.5, U1.49 (PA14)
SWDIO: J2.6, U1.46 (PA13)
SWO: J2.10, U1.55 (PB3)
UART_RX: J2.3, U1.15 (PA1)
UART_TX: J2.4, U1.14 (PA0)

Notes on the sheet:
External GPS Connector
Programming Connector
Stack Connector
Hieranchical sheets
Caurin v.2.0
STM32L476RGT6
Telecommunications
Peripherals

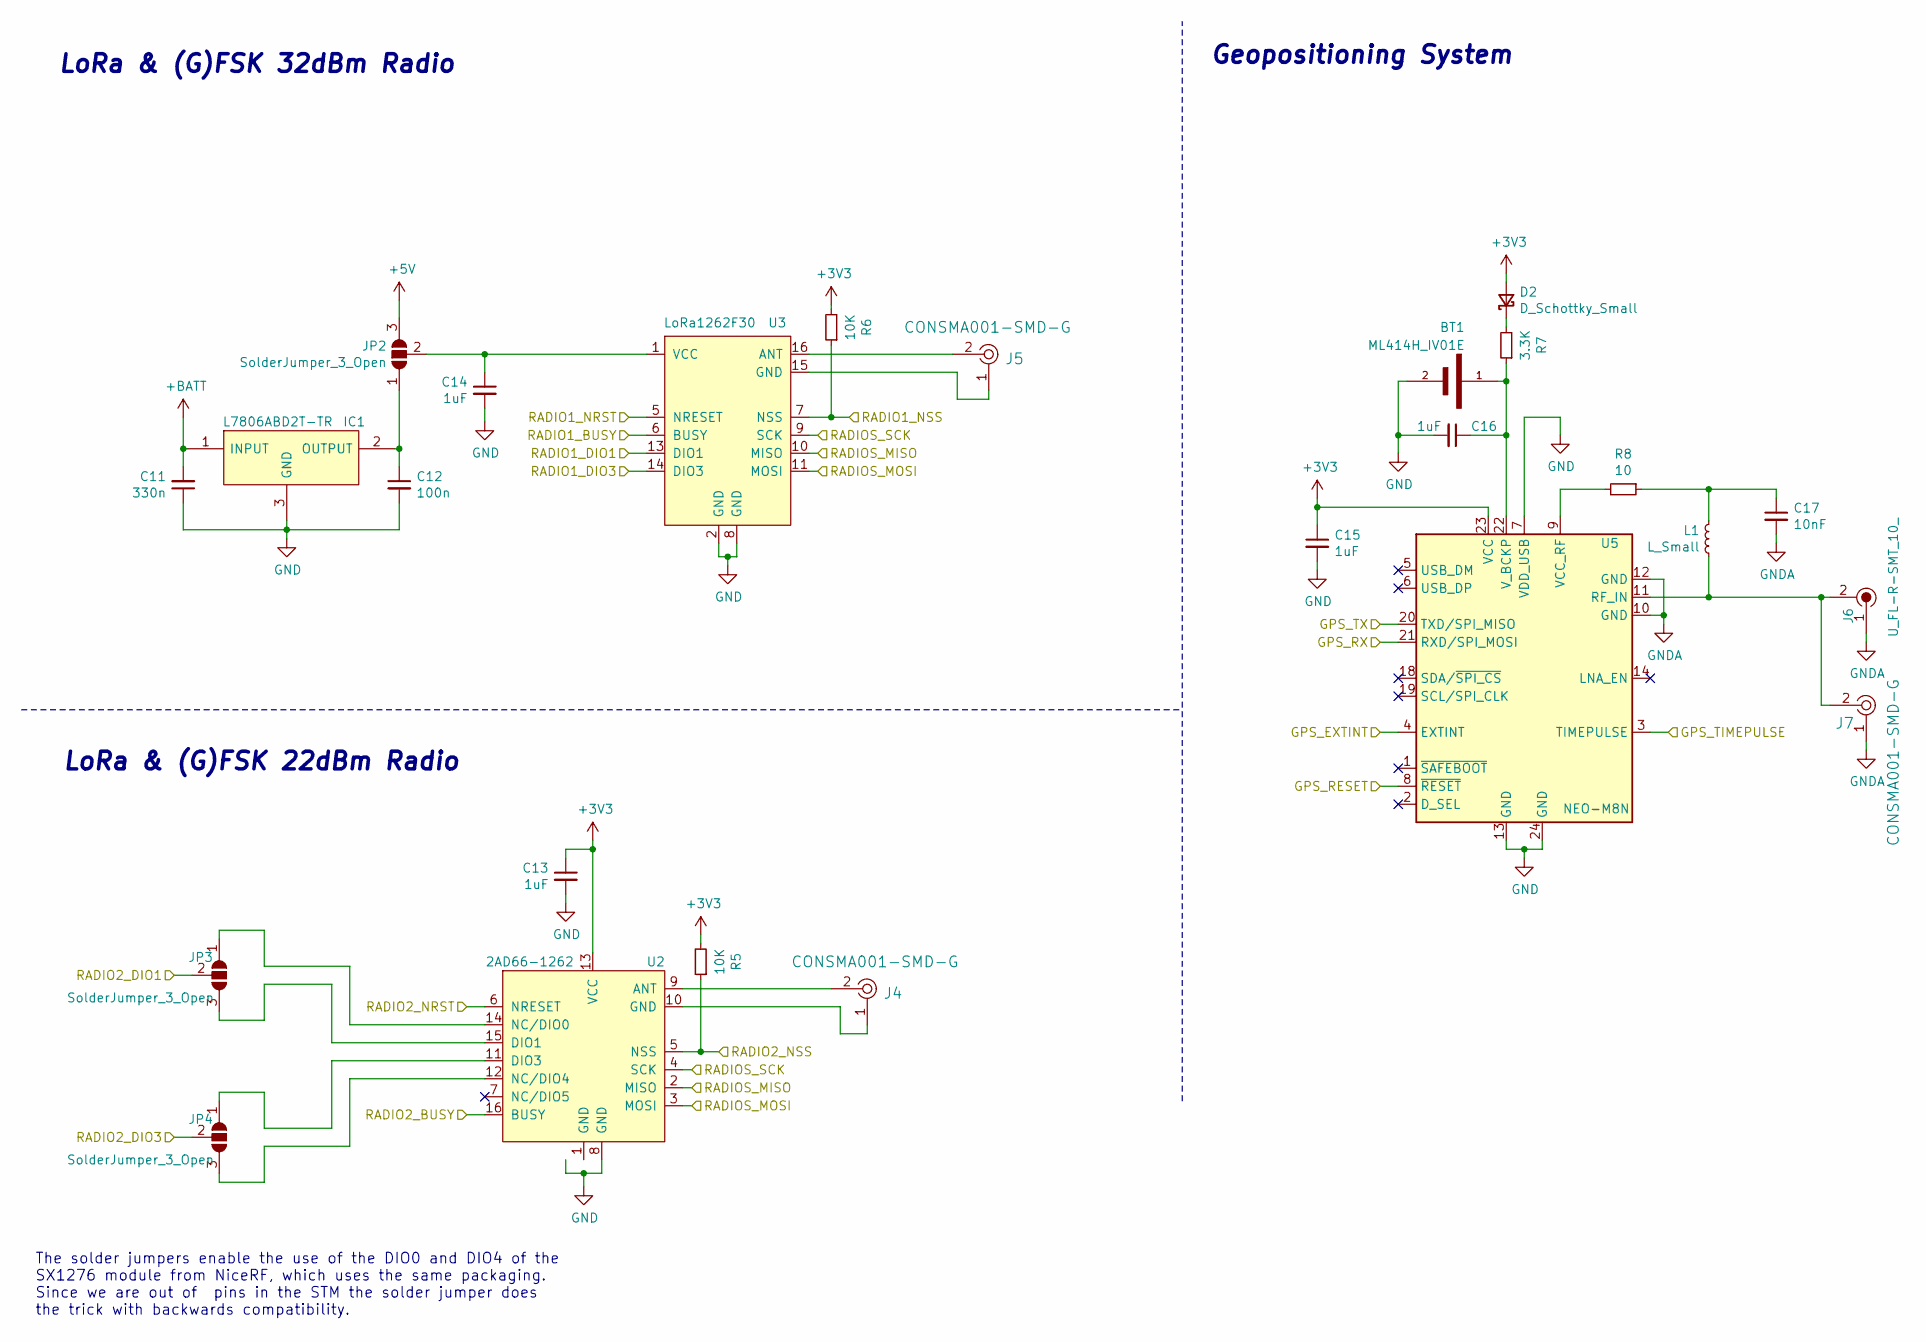
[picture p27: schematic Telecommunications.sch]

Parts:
BT1: ML414H_IV01E; SEIKO_ML414H_IV01E
C11: 330n; C_0805_2012Metric
C12: 100n; C_0805_2012Metric
C13, C14, C15, C16: 1uF; C_0805_2012Metric
C17: 10nF; C_0603_1608Metric
D2: D_Schottky_Small; D_0603_1608Metric
IC1: L7806ABD2T-TR; ST_D2PAK; Mouser Part Number 511-L7806ABD2T-TR
J4, J5, J7: CONSMA001-SMD-G; RF_SMA_Vertical_5-1814832-1; MPN CONSMA001-SMD-G; Digi-Key_PN CONSMA001-SMD-G-ND
J6: U_FL-R-SMT_10_; Coax_Conn_U.FL; MPN U.FL-R-SMT(10); Digi-Key_PN H9161CT-ND
JP2, JP3, JP4: SolderJumper_3_Open; SolderJumper-3_P1.3mm_Open_RoundedPad1.0x1.5mm_NumberLabels
L1: L_Small; L_0402_1005Metric_Pad0.77x0.64mm_HandSolder
R5, R6: 10K; R_0805_2012Metric
R7: 3.3K; R_0805_2012Metric
R8: 10; R_0603_1608Metric
U2: 2AD66-1262; 2AD66-126x
U3: LoRa1262F30
U5: NEO-M8N; ublox_NEO

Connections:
5V: JP2.3 (B); also elsewhere on the board
BAT+: C11.2, IC1.1 (INPUT); also elsewhere on the board
GND: BT1.2, C11.1, C12.2, C13.2, C14.2, C15.2, C16.2, IC1.3 (GND), U2.8 (GND), U3.2 (GND), U3.8 (GND), U5.7 (VDD_USB), U5.13 (GND), U5.24 (GND); also elsewhere on the board
GNDA: C17.2, J6.1, J7.1, U5.10 (GND), U5.12 (GND)
GPS_EXTINT: U5.4 (EXTINT); also elsewhere on the board
GPS_RESET: U5.8 (~RESET); also elsewhere on the board
GPS_RX: U5.21 (RXD/SPI_MOSI); also elsewhere on the board
GPS_TIMEPULSE: U5.3 (TIMEPULSE); also elsewhere on the board
GPS_TX: U5.20 (TXD/SPI_MISO); also elsewhere on the board
unnamed: BT1.1, C16.1, R7.1, U5.22 (V_BCKP)
unnamed: C12.1, IC1.2 (OUTPUT), JP2.1 (A)
unnamed: C14.1, JP2.2 (C), U3.1 (VCC)
unnamed: C17.1, L1.1, R8.1
unnamed: D2.1 (K), R7.2
unnamed: J4.1, U2.10 (GND)
unnamed: J4.2, U2.9 (ANT)
unnamed: J5.1, U3.15 (GND)
unnamed: J5.2, U3.16 (ANT)
unnamed: J6.2, J7.2, L1.2, U5.11 (RF_IN)
unnamed: JP3.1 (A), U2.14 (NC/DIO0)
unnamed: JP3.3 (B), U2.15 (DIO1)
unnamed: JP4.1 (A), U2.11 (DIO3)
unnamed: JP4.3 (B), U2.12 (NC/DIO4)
unnamed: R8.2, U5.9 (VCC_RF)
RADIO1_BUSY: U3.6 (BUSY); also elsewhere on the board
RADIO1_DIO1: U3.13 (DIO1); also elsewhere on the board
RADIO1_DIO3: U3.14 (DIO3); also elsewhere on the board
RADIO1_NRST: U3.5 (NRESET); also elsewhere on the board
RADIO1_NSS: R6.1, U3.7 (NSS); also elsewhere on the board
RADIO2_BUSY: U2.16 (BUSY); also elsewhere on the board
RADIO2_DIO1: JP3.2 (C); also elsewhere on the board
RADIO2_DIO3: JP4.2 (C); also elsewhere on the board
RADIO2_NRST: U2.6 (NRESET); also elsewhere on the board
RADIO2_NSS: R5.1, U2.5 (NSS); also elsewhere on the board
SPI1_MISO: U2.2 (MISO), U3.10 (MISO); also elsewhere on the board
SPI1_MOSI: U2.3 (MOSI), U3.11 (MOSI); also elsewhere on the board
SPI1_SCK: U2.4 (SCK), U3.9 (SCK); also elsewhere on the board

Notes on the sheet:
Geopositioning System
LoRa & (G)FSK 32dBm Radio
LoRa & (G)FSK 22dBm Radio
The solder jumpers enable the use of the DIO0 and DIO4 of the SX1276 module from NiceRF, which uses the same packaging. Since we are out of pins in the STM the solder jumper does the trick with backwards compatibility.

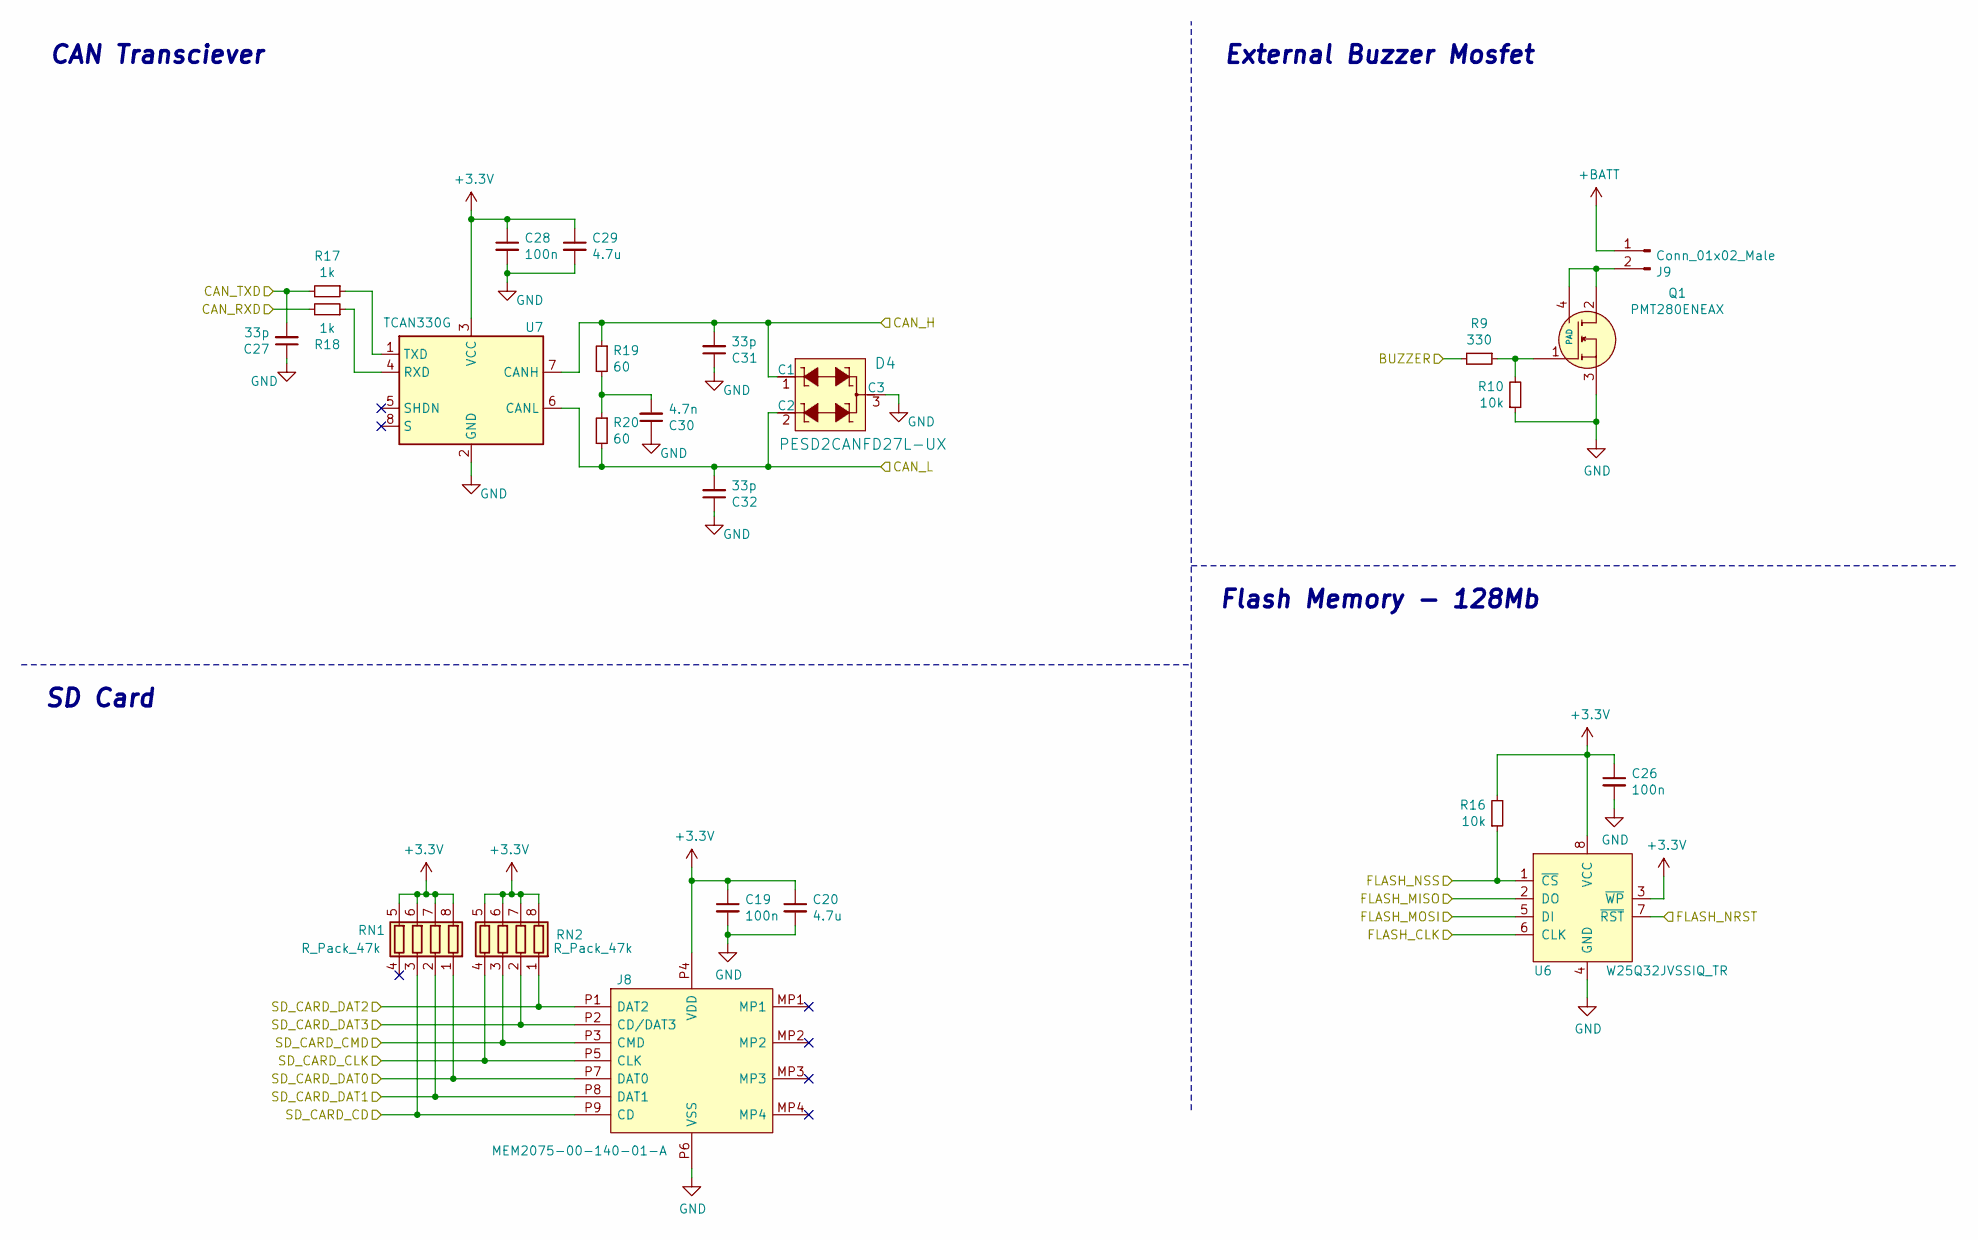
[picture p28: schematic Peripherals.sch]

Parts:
C19, C26, C28: 100n; C_0805_2012Metric
C20, C29: 4.7u; C_0805_2012Metric
C27, C31, C32: 33p; C_0805_2012Metric
C30: 4.7n; C_0805_2012Metric
D4: PESD2CANFD27L-UX; SOT-23-3; MPN PESD2CAN,215; Digi-Key_PN 1727-3891-1-ND
J8: MEM2075-00-140-01-A; MEM20750014001A; Mouser Part Number 640-MEM20750014001A
J9: Conn_01x02_Male; JST_EH_B2B-EH-A_1x02_P2.50mm_Vertical
Q1: PMT280ENEAX; SOT230P700X180-4N; Mouser Part Number 771-PMT280ENEAX
R9: 330; R_0805_2012Metric
R10, R16: 10k; R_0805_2012Metric
R17, R18: 1k; R_0805_2012Metric
R19, R20: 60; R_0805_2012Metric
RN1, RN2: R_Pack_47k; YC164JR07220RL
U6: W25Q32JVSSIQ_TR; SOIC-8_W5.6mm; MPN W25Q32JVSSIQ TR; Digi-Key_PN W25Q32JVSSIQCT-ND
U7: TCAN330G; SOIC-8_3.9x4.9mm_P1.27mm

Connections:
BAT+: J9.1; also elsewhere on the board
CAN_H: C31.2, D4.1 (C1), R19.1, U7.7 (CANH); also elsewhere on the board
CAN_L: C32.2, D4.2 (C2), R20.2, U7.6 (CANL); also elsewhere on the board
CAN_RX: R18.2; also elsewhere on the board
CAN_TX: C27.2, R17.2; also elsewhere on the board
EXT_BUZZER: R9.2; also elsewhere on the board
FLASH_NRST: U6.7 (~RST); also elsewhere on the board
FLASH_NSS: R16.1, U6.1 (~CS); also elsewhere on the board
FLASH_SPI_CLK: U6.6 (CLK); also elsewhere on the board
FLASH_SPI_MISO: U6.2 (DO); also elsewhere on the board
FLASH_SPI_MOSI: U6.5 (DI); also elsewhere on the board
GND: C19.2, C20.2, C26.2, C27.1, C28.2, C29.2, C30.1, C31.1, C32.1, D4.3 (C3), J8.P6 (VSS), Q1.3, R10.1, U6.4 (GND), U7.2 (GND); also elsewhere on the board
unnamed: C30.2, R19.2, R20.1
unnamed: J9.2, Q1.2, Q1.4 (PAD)
unnamed: Q1.1, R9.1, R10.2
unnamed: R17.1, U7.1 (TXD)
unnamed: R18.1, U7.4 (RXD)
SD_CARD_CD: J8.P9 (CD), RN1.3 (R3.1); also elsewhere on the board
SD_CARD_CLK: J8.P5 (CLK), RN2.4 (R4.1); also elsewhere on the board
SD_CARD_CMD: J8.P3 (CMD), RN2.3 (R3.1); also elsewhere on the board
SD_CARD_DAT0: J8.P7 (DAT0), RN1.1 (R1.1); also elsewhere on the board
SD_CARD_DAT1: J8.P8 (DAT1), RN1.2 (R2.1); also elsewhere on the board
SD_CARD_DAT2: J8.P1 (DAT2), RN2.1 (R1.1); also elsewhere on the board
SD_CARD_DAT3: J8.P2 (CD/DAT3), RN2.2 (R2.1); also elsewhere on the board

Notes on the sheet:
CAN Transciever
SD Card
Flash Memory - 128Mb
External Buzzer Mosfet

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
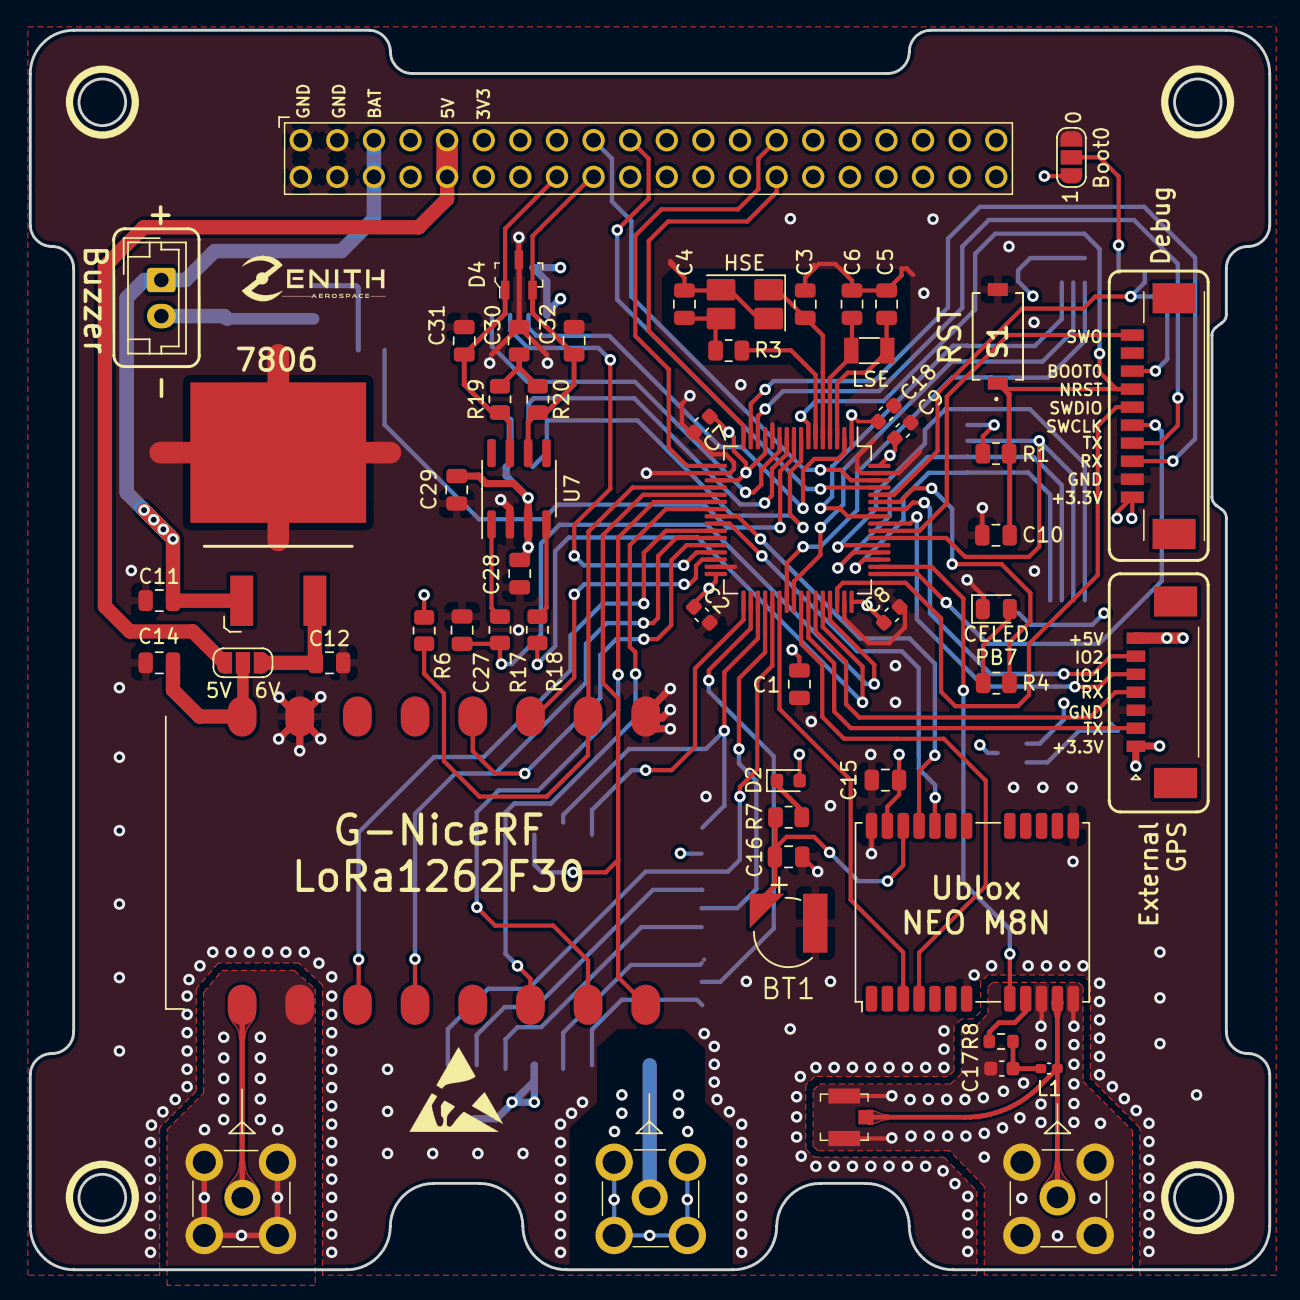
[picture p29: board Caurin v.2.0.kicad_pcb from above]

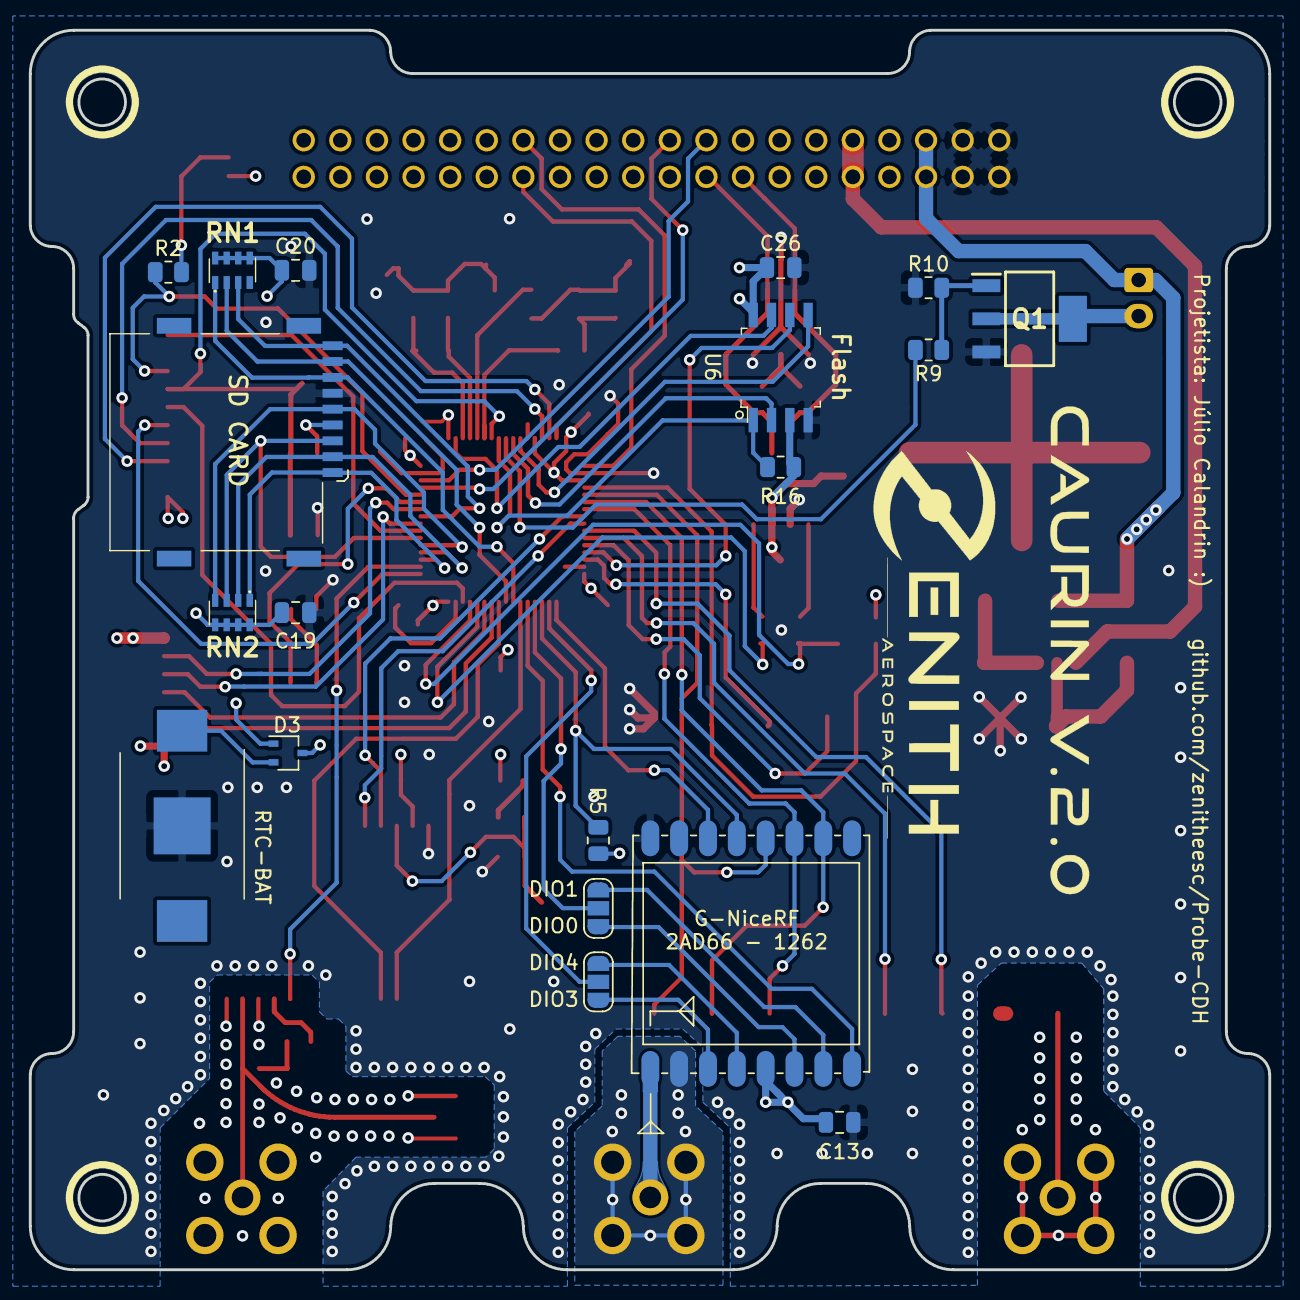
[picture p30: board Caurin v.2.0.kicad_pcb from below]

Board: 4 copper layers, 86.0 x 86.0 mm, 75 parts (19 on the bottom side), 85 nets.

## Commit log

2022-01-18 Add the actual board.
    [Caurin v.2.0.kicad_pcb, Caurin v.2.0.sch, ModelStack.dxf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]
2022-01-19 Update 7806 Traces
    [Caurin v.2.0.kicad_pcb]
2022-01-20 Add shapes3D folder
    Now all 3D models for the components are stored in a single folder, thanks to the Archive Plugin from https://github.com/MitjaNemec/Kicad_action_plugins.git
    [2AD6-1262 G-NiceRF.step, 533980771 recolored.step, 533981071 recolored.step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]
2022-02-04 Add RTC backup battery
    Add the CR1025 RTC Button Cell Battery. Update schematic images and PDF.
    [Caurin v.2.0.kicad_pcb, Caurin v.2.0.sch, SOT-323_SC-70.step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]
2022-02-05 Update RTC Battery silk screen name
    [Caurin v.2.0.kicad_pcb]
2022-07-14 Add solder jumper for DIO pins.
    Adds solder jumper for DIO pin compatibility between SX1276 and SX1262 low power radios.
    Also added the name of the designer (me).
    [Caurin v.2.0.kicad_pcb, Telecommunications.sch]

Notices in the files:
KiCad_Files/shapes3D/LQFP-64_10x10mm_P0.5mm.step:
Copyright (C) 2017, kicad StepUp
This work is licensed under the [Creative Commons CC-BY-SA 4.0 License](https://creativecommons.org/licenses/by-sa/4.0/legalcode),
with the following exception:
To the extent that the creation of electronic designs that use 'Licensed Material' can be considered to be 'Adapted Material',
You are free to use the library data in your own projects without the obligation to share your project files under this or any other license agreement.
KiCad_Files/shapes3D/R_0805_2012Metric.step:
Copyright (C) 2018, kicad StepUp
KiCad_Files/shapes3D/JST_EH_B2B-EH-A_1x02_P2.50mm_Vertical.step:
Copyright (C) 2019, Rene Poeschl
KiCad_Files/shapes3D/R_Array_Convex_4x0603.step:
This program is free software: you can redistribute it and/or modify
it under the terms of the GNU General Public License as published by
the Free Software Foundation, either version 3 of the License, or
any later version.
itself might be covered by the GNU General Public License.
